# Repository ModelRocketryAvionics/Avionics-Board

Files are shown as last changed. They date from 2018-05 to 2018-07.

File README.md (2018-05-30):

# ModelRocketAvionicsPCB
'Cheap', Easy Avionics for Model Rockets!

Howdy! This is a repo for an avionics board designed for small scale model rockets. The goal of the project is to provide an easy to integrate system that provides telemetry data measurements. 

The main features are:
- 3 DOF Accelerometer (upto 24g)
- 3 DOF Gyroscope
- Barometric Pressure/Altitude sensor
- microSD Card data storage
- USB for charging, reprogramming and microSD card reading*
- Expansion header for future functionality called "Stages" (see below)

*Usb programming and microSD card reading probably won't be implemented initially.

Potential/Planned Stages/Expansion Boards:
- Radio link/communications (Provides real-time telemetry data over a short range wireless link)
- Relay/Switcher (Provides high-power switching for ignition of additional charges/engines, deploy parachutes, etc)
- Additional Sensors Expansions (Additional Sensors like GPS, etc)

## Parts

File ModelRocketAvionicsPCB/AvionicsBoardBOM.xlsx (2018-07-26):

Avionics Board BOM
Reference Part Numbers | Reference Name | Digikey Part Number | Quantitity
U1 | TM4C123GH6PM | 296-46360-1-ND | 1
R1, R15 | 100 Ohm 402 | P100DECT-ND | 2
P1 | FTSH-105-01-F-DV | SAM8796-ND | 1
R2, R3, R4, R9, R10, R11, R14 | 10k Ohm 402 | ‎CR0402-FX-1002GLF‎ (https://www.digikey.ca/product-detail/en/bourns-inc/CR0402-FX-1002GLF/CR0402-FX-1002GLFCT-ND/3592879) | 7
C1, C3, C5 | 0.01uF 402 | 1276-1494-1-ND | 3
C2, C4, C7, C8, C14, C22, C23, C24, C26, C27 | 0.1uF 402 | 490-6322-1-ND | 10
C6, C9, C11, C12, C13, C25 | 1uF 603 | 1276-1102-1-ND | 6
C10, C31 | 2.2uF 603 | 490-3296-1-ND | 1
R5, R6 | 4.7k Ohm 402 | P4.7KDCCT-ND | 2
C19, C21 | 10uF 1206 Pol | 478-10756-1-ND | 2
U5 | MPL3115A2 | MPL3115A2-ND | 1
U3 | LIS331 | 497-10134-ND | 1
C20 | 10uF 603 | 1276-1871-1-ND | 1
C28 | 10nF 402 | 445-5584-1-ND | 1
U4 | L3GD2-HTR | 497-13931-1-ND | 1
P2 | USB_Connector_ZX62-B-5PA | H125279CT-ND | 1
CON1 | microSD_Card | WM11190CT-ND | 1
C17, C18 | 24pF 402 | 1276-1670-1-ND | 2
C15, C16 | 10pF 402 | ‎GJM1555C1H100GB01D‎ (https://www.digikey.ca/product-detail/en/murata-electronics-north-america/GJM1555C1H100GB01D/490-8077-1-ND/4380363) | 2
Y1 | 16MHz | 631-1150-1-ND | 1
Y2 | 32.768kHz | 535-9034-ND | 1
U8, U9 | 16pin Female Headers | S7014-ND | 2
D3 | Geend Small LED 603 | 160-1435-1-ND | 1
P3 | JST-2 | 455-1611-ND | 1
U10 | DMG1029SV-7 | DMP2004VKDICT-ND | 1
U11 | CSS-1210TB | 563-1091-1-ND | 1
C29, C30 | 4.7uF 603 | 445-7478-1-ND | 2
C32 | 470pF 402 | 490-1300-1-ND | 1
R13 | 330 Ohm 402 | RR05P330DCT-ND | 1
D1 | Small Red LED 603 | 160-1447-1-ND | 1
D2 | B340A | B340A-FDICT-ND | 1
U6 | MCP73831 | MCP73831T-2ACI/OTCT-ND | 1
U7 | MIC5219-3.3BM5 | 576-1281-1-ND | 1
Total Number of Parts per Board |  |  | 62

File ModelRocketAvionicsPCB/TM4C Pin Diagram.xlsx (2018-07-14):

TM4C123G Pin Allocation and Function Descriptions |  |  |  |  |  |  |  |  |  | Yes
Pin Number | GPIO Name | Available | Net Name | Description Of Function | Other Functions/Peripherals |  |  |  |  | No
1 | PB6 | Yes | GRY_INT2/DRDY | Gyroscope Sensor Interrupt Pin |  |  |  |  |  | RSV
2 | VDDA | No | PWR_VDDA | Analog Power Supply+
3 | GNDA | No | PWR_GND | Analog Power Supply- (Connected to PWR_GND)
4 | PB7 | Yes | GYR_INT1 | Gyroscope Sensor Interrupt Pin
5 | PF4 | Yes | GYR_DEN | Gyroscope Data Enable Pin | `
6 | PE3 | Yes | ACC_INT1 | Accelrometer Sensor Interrupt Pin |  |  |  | PF4/SW1 | User Push Button 1
7 | PE2 | Yes | ACC_INT2 | Accelrometer Sensor Interrupt Pin
8 | PE1 | Yes
9 | PE0 | Yes
10 | PD7 | Yes
11 | VDD | No | PWR_VDD | Main Positive Power Supply
12 | GND | No | PWR_GND | Main Negative Power Supply |  | ACC_INT2 | Accelrometer Sensor Interrupt Pin
13 | PC7 | Yes |  |  |  | GYR_INT1 | Gyroscope Sensor Interrupt Pin
14 | PC6 | Yes |  |  |  | GRY_INT2/DRDY | Gyroscope Sensor Interrupt Pin
15 | PC5 | Yes |  |  |  | GYR_DEN | Gyroscope Data Enable Pin
16 | PC4 | Yes |  |  |  | ACC_INT1 | Accelrometer Sensor Interrupt Pin
17 | PA0 | RSV | PA0/U0Rx | UART0 Receive, Used in FTDI Header for debug/programming
18 | PA1 | RSV | PA1/U0Tx | UART0 Transmit, Used in FTDI Header for debug/programming
19 | PA2 | No | PA2/SSI0CLK | SPI0 Clock, Used for microSD Card or SPI Flash
20 | PA3 | No | PA3/SSI0Fss | SPI0 Chip Select, Used for microSD Card or SPI Flash
21 | PA4 | No | PA4/SSI0Rx | SPI0 Receive, Used for microSD Card or SPI Flash
22 | PA5 | No | PA5/SSI0Tx | SPI0 Transmit, Used for microSD Card or SPI Flash
23 | PA6 | Yes
24 | PA7 | Yes
25 | VDDC | No | PWR_VDDC | Internal Positive Power Supply
26 | VDD | No | PWR_VDD | Main Positive Power Supply
27 | GND | No | PWR_GND | Main Negative Power Supply
28 | PF0 | No | PF0/SW2 | User Push Button 2 and MCU Wake
29 | PF1 | No | PF1/LED_R | User Red LED, cut jumper for: GPIO, PWM Output (M1P5)
30 | PF2 | Yes | BAR_INT1 | Interrupt Pin for Barometer Sensor
31 | PF3 | Yes | BAR_INT2 | Interrupt Pin for Barometer Sensor
32 | WAKE | No | WAKE | Wake pin for low power
33 | HIB | RSV | HIB | Hibernation Output (For turning off regulator)
34 | XOSC0 | No | XOSC0 | 32.768kHz Crystal
35 | GNDX | No | XGND | 32.768kHz Crystal
36 | XOSC1 | No | XOSC1 | 32.768kHz Crystal
37 | VBAT | No | PWR_VBAT | Connected to PWR_VDD
38 | RST | No | RESET | MCU Reset (Connected to Push button)
39 | GND | No | PWR_GND | Main Negative Power Supply
40 | OSC0 | No | OSC0 | Main Oscillator 0
41 | OSC1 | No | OSC1 | Main Oscillator 0
42 | VDD | No | PWR_VDD | Main Positive Power Supply
43 | PD4 | No | USB0_DM | USB 0 Data Minus
44 | PD5 | No | USB0_DP | USB 0 Data Plus
45 | PB0 | No | PB0/USB0_ID | USB 0 OTG Id
46 | PB1 | No | PB1/USB0_VBUS | USB 0 VBUS Power Supply (5V tolerant)
47 | PB2 | No | PB2/I2C_SCL | I2C0 Clock
48 | PB3 | No | PB3/I2C_SDA | I2C0 Data
49 | PC3 | No | PC3/JTAG_TDO | JTAG Programming/Debug TDO Pin
50 | PC2 | No | PC2/JTAG_TDI | JTAG Programming/Debug TDI Pin
51 | PC1 | No | PC1/JTAG_TMS | JTAG Programming/Debug TMS Pin
52 | PC0 | No | PC0/JTAG_TCK | JTAG Programming/Debug TCK Pin
53 | PD6 | Yes
54 | VDD | No | PWR_VDD | Main Positive Power Supply
55 | GND | No | PWR_GND | Main Negative Power Supply
56 | VDDC | No | PWR_VDDC | Internal Positive Power Supply
57 | PB5 | Yes
58 | PB4 | Yes
59 | PE4 | Yes | PE4/U5Rx | UART 5 Receive
60 | PE5 | Yes | PE5/U5Tx | UART 5 Transmit
61 | PD0 | Yes | PD0/SSI1CLK | SPI1 Clock | PWM Output (M1P0)
62 | PD1 | Yes | PD1/SSI1Fss | SPI1 Chip Select | PWM Output (M1P1)
63 | PD2 | Yes | PD2/SSI1Rx | SPI1 Receive | Analog Input 5
64 | PD3 | Yes | PD3/SSI1Tx | SPI1 Transmit | Analog input 4
 |  |  |  |  | Total Header Pins
Headers | Left | Right
1 | PWR_GND | +VBAT
2 | PWR_GND | +VBAT
3 | I2C_SCL | 3V3
4 | I2C_SDA | 3V3
5 | 53 | WAKE
6 | RESET | 24
7 | 33 | 23
8 | 57 | 18
9 | 58 | 17
10 | 59 | 16
11 | 60 | 15
12 | 61 | 14
13 | 62 | 13
14 | 63 | 10
15 | 64 | 9
16 | 3V3 | PWR_GND
 | 33 | 24
 | I2C_SCL | 23
 | I2C_SDA | 18
 | Reset | 17
 | 53 | 16
 | 57 | 15
 | 58 | 14
 | 59 | 13
 | 60 | 10
 | 61 | 9
 | 62 | 8
 | 63 | 7
 | 64 | 6
 |  | 5
 |  | 4
 |  | 1

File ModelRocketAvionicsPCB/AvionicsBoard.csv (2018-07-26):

Id | Designator | Package | Quantity | Designation | Supplier and ref
1 | C1,C3,C5 | C_0402 | 3 | 0.01uF
2 | C2,C4,C7,C8,C14,C22,C24,C27 | C_0402 | 8 | 0.1uF
3 | C6,C9,C11,C12,C13,C25 | C_0603 | 6 | 1uF
4 | C10,C31 | C_0603 | 2 | 2.2uF
5 | C15,C16 | C_0402 | 2 | 10pF
6 | C17,C18 | C_0402 | 2 | 24pF
7 | C20 | C_0603 | 1 | 10uF
8 | C23,C26 | C_0402 | 2 | .1uF
9 | C28 | C_0402 | 1 | 10nF(25V)
10 | C29,C30 | C_0603 | 2 | 4.7uF
11 | C32 | C_0402 | 1 | 470pF
12 | microSD_Card | Micro_SD_WM11190CT | 1 | microSD_Card
13 | D1 | R_0603 | 1 | RED
14 | D2 | B340A | 1 | B340A
15 | P1 | FTSH-105-01-F-DV-K | 1 | FTSH-105-01-F-DV
16 | P3 | JST_B2B-EH-A(LF)(SN) | 1 | JST-2
17 | R1,R15 | R_0402 | 2 | 100
18 | R2,R3,R4,R9,R10,R11,R14 | R_0402 | 7 | 10k
19 | R5,R6 | R_0402 | 2 | 4.7k
20 | R13 | R_0402 | 1 | 330
21 | U1 | TM4C123GH6PMI | 1 | TM4C123GH6PM
22 | U3 | LIS331HH | 1 | LIS331
23 | U4 | Gyro_L3GD20HTR | 1 | L3GD20HTR
24 | U5 | MPL3115A2 | 1 | MPL3115A2
25 | U6 | MCP73831T-2ACI&slash_OT | 1 | MCP73831
26 | U7 | MIC5219-3.3YM5-TR | 1 | MIC5219-3.3BM5
27 | Y1 | 16MHz_Clock | 1 | 16Mhz
28 | P2 | USB_Connector_ZX62-B-5PA | 1 | USB_OTG
29 | JP1,JP3 | NO_Jumper | 2 | Jumper_NO_Small
30 | JP2,JP4 | NC_Jumper | 2 | Jumper_NC_Small
31 | C19,C21 | C_1206 | 2 | 10uF
32 | Y2 | Crystal_32768Hz_Radial_Can | 1 | 32.768kHz
33 | D3 | R_0603 | 1 | Led_Small
34 | U8,U9 | 16x1_Female_Header | 2 | CONNHeaderFemale16
35 | Off U11 On | CSS-1210TB | 1 | CSS-1210TB
36 | U10 | SOT563 | 1 | DMG1029SV-7

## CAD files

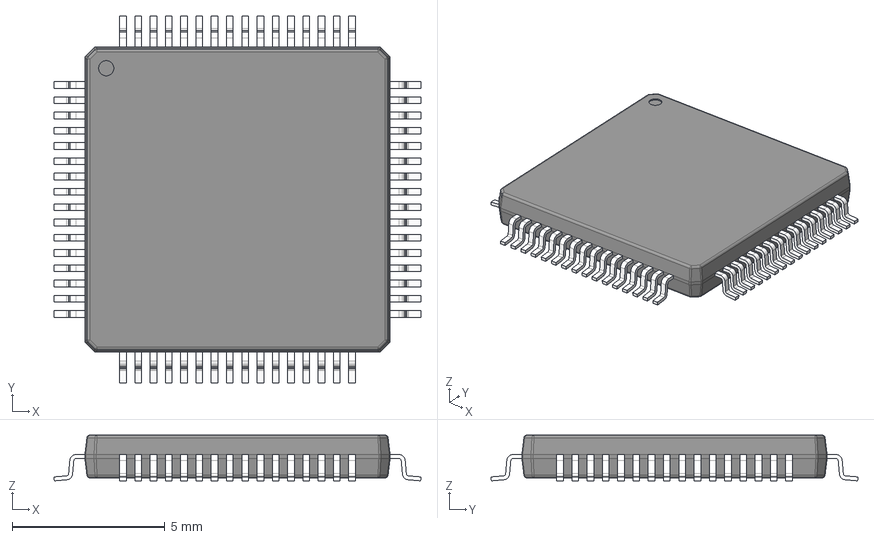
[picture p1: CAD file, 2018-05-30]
ModelRocketAvionicsPCB/PM0064A.stp
12.0 x 12.0 x 1.50 mm
BODY-QFP
LEAD-QFP x 64

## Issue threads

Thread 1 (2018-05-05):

TM4C123GH6PM Schematic is missing pin 60 (PE5)

Michael-Graves, 2018-05-05:
Currently unused so shouldn't cause any problems.

Closed 2018-05-07.

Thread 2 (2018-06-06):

USB Shield to GND

HarrisonHandley, 2018-06-06:
Need to check if all mounting pads for the USB connector should be connected to GND.

Michael-Graves, 2018-06-06:
It should

HarrisonHandley, 2018-06-06:
There's 6 pads for connecting the shield to the PCB. 4 of them have a no trace zone surrounding them. The 2 closest pads to the data pins aren't in that zone and are currently connected to GND.

Closed 2018-06-16.

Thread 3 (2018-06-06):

Jumper Footprints

HarrisonHandley, 2018-06-06:
The jumper Footprints for both NO and NC need to be done along with selecting the components.

Michael-Graves, 2018-06-06:
Can just do solder/cut jumpers where you can cut a trace or solder 2 pads together to select the state, won't need any components.

HarrisonHandley, 2018-06-06:
Should we leave the footprints at 0603 size, and then later you can connect the pads with wire. Or for the NC connections when we assemble the board.

Michael-Graves, 2018-06-06:
We should make custom footprints for NC and NO. but essentially its just a 0603 footprint with a wire between them and no solder mask

Closed 2018-06-16.

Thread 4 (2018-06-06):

Polarized Capacitors

HarrisonHandley, 2018-06-06:
Need to check if the polarized Capacitors on the sensors are required and if a SMD non-polarized cermaic capacitor can be used instead.

Michael-Graves, 2018-06-06:
Changed polarized caps to use this part: 478-10756-1-ND (1206)

Closed 2018-06-06.

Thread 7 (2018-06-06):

Allocate pins for Sensor GPIO

Michael-Graves, 2018-06-06:
Sensors need a few pins allocated for interrupts and enables. We should probably wire these in to whichever pin is convenient once we've placed the other components.

Closed 2018-06-16.

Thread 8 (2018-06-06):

Connect Headers to extra pins for Shields

HarrisonHandley, 2018-06-06:
Need to connect Headers to the extra TM4C123 and power pins so Shields can be added on later.

Michael-Graves, 2018-06-06:
~Shields~ Stages

Closed 2018-07-15.

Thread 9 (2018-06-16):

Jumper Footprint issues in Layout

HarrisonHandley, 2018-06-16:
Can't attach traces to the jumper footprints.

Closed 2018-07-15.

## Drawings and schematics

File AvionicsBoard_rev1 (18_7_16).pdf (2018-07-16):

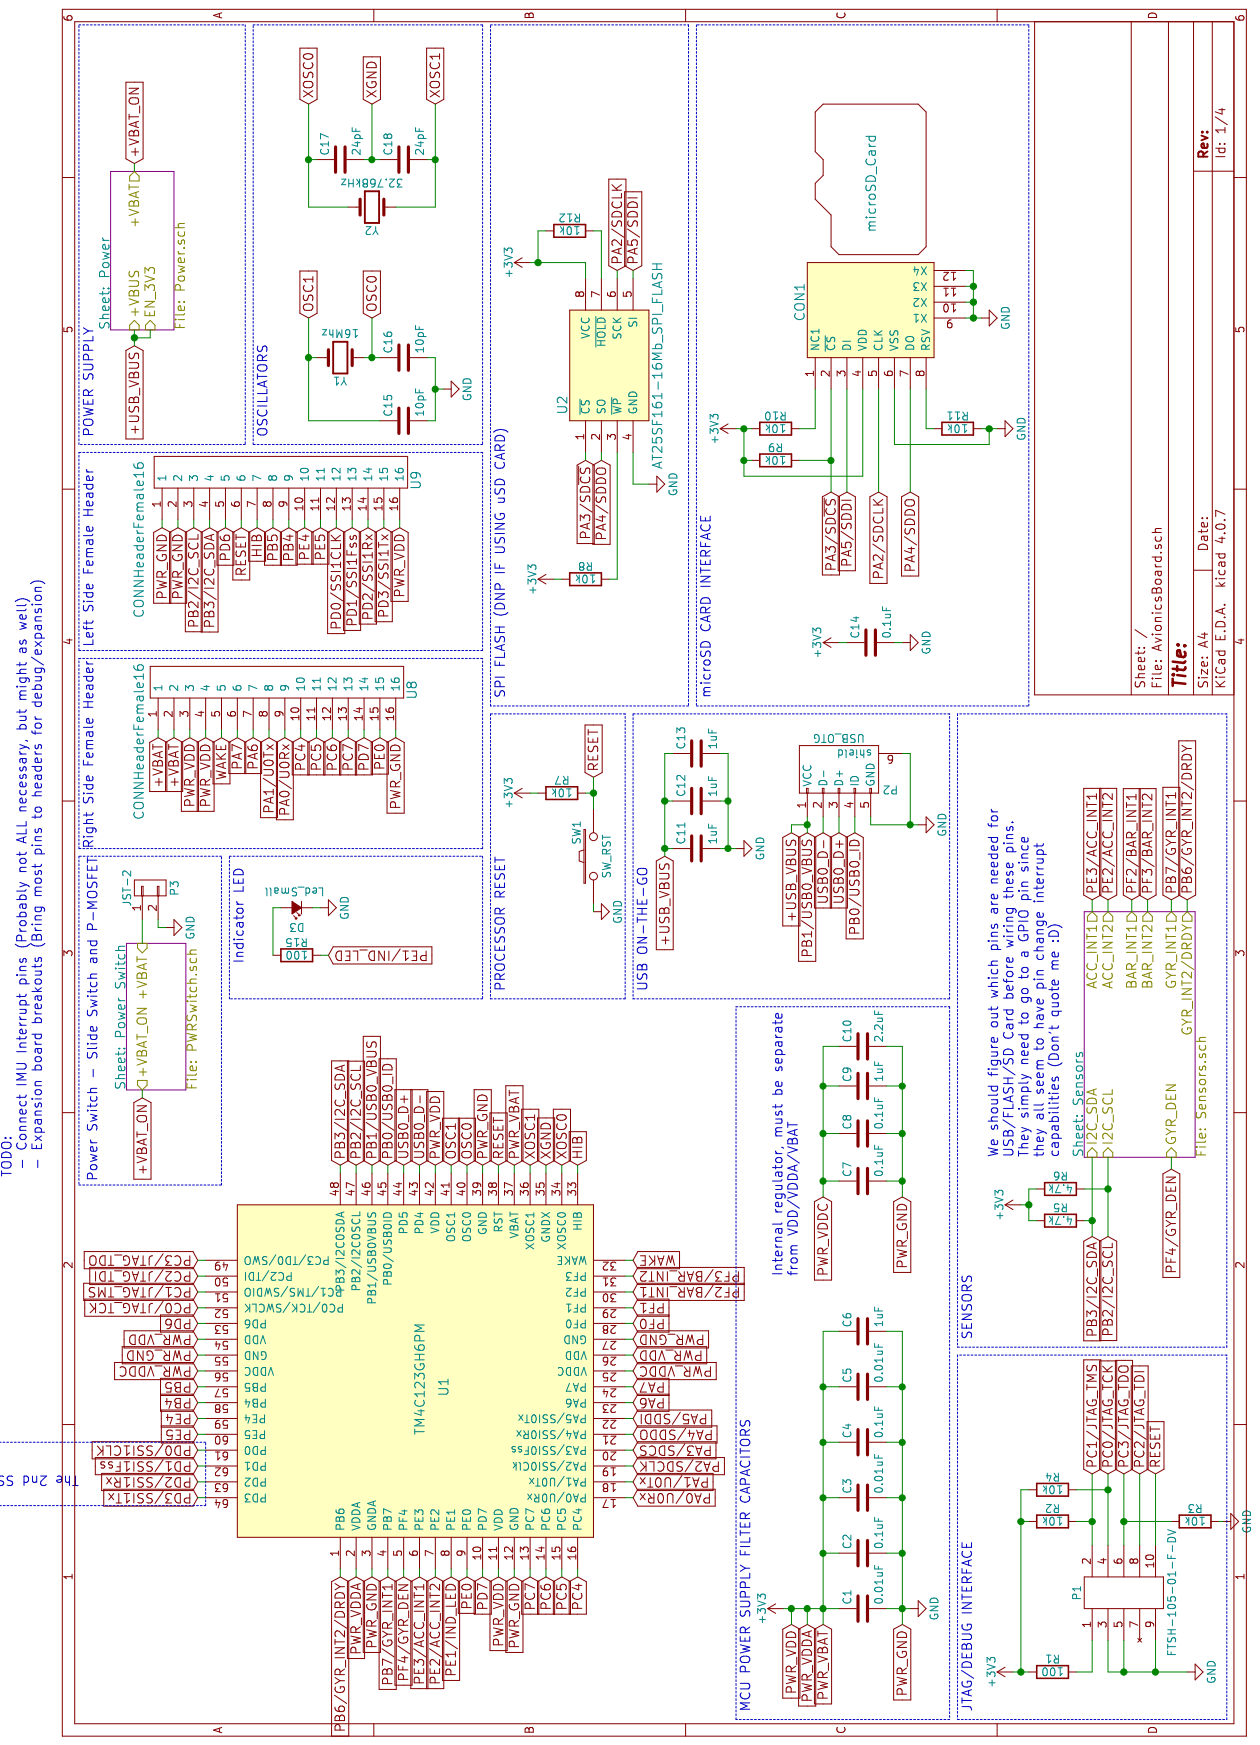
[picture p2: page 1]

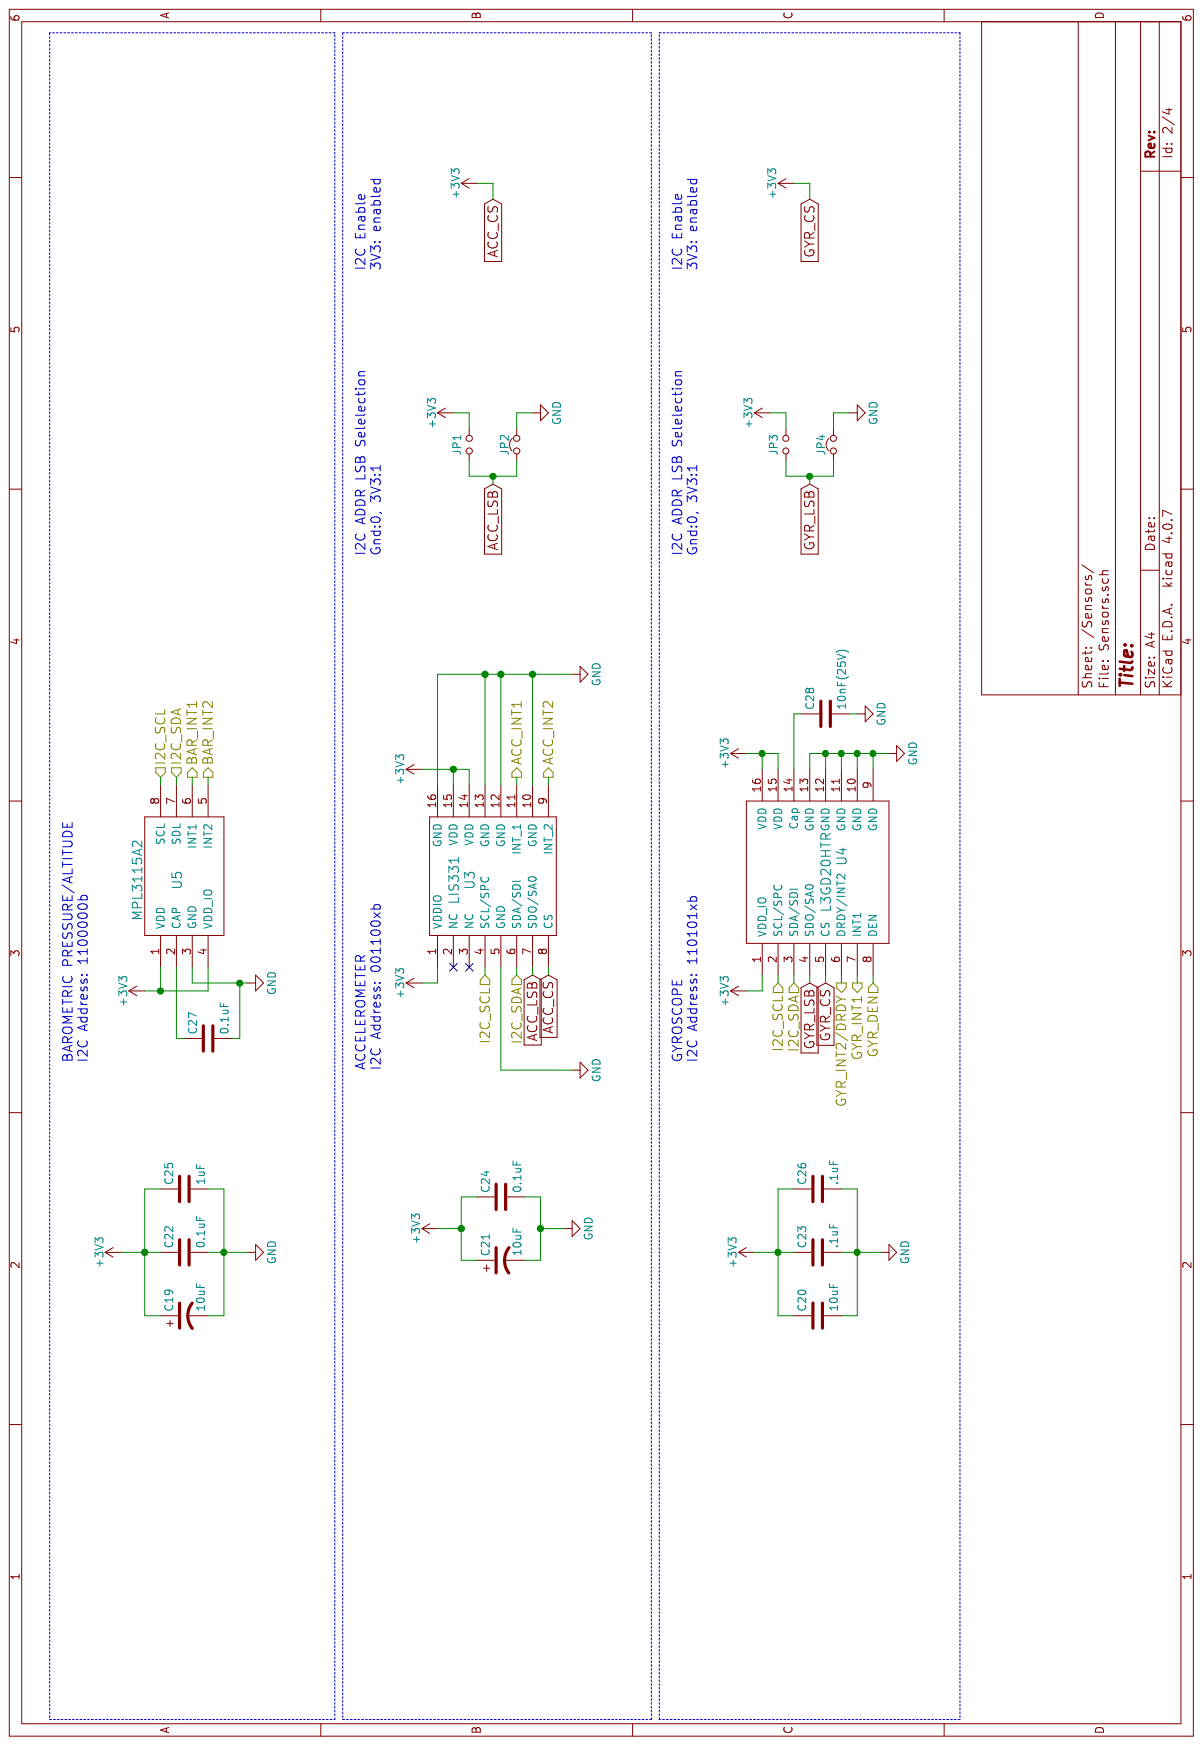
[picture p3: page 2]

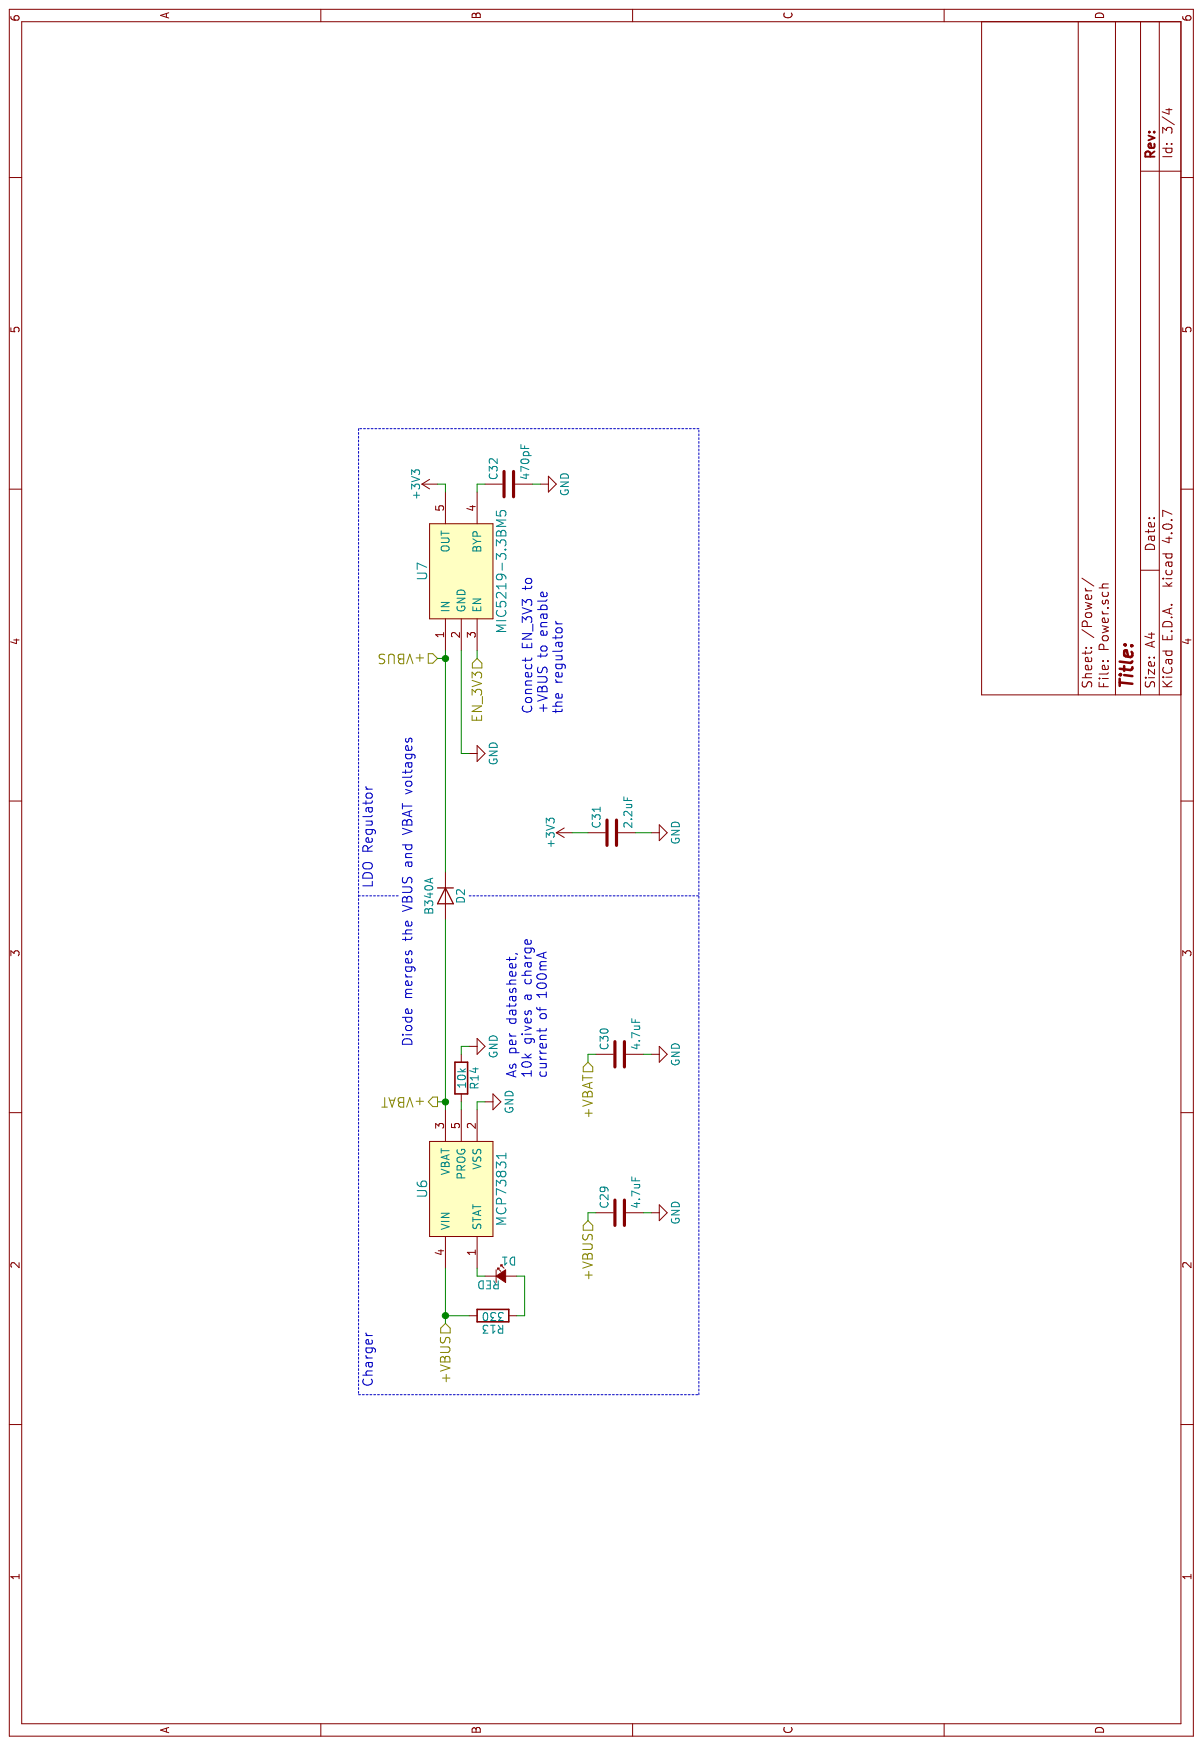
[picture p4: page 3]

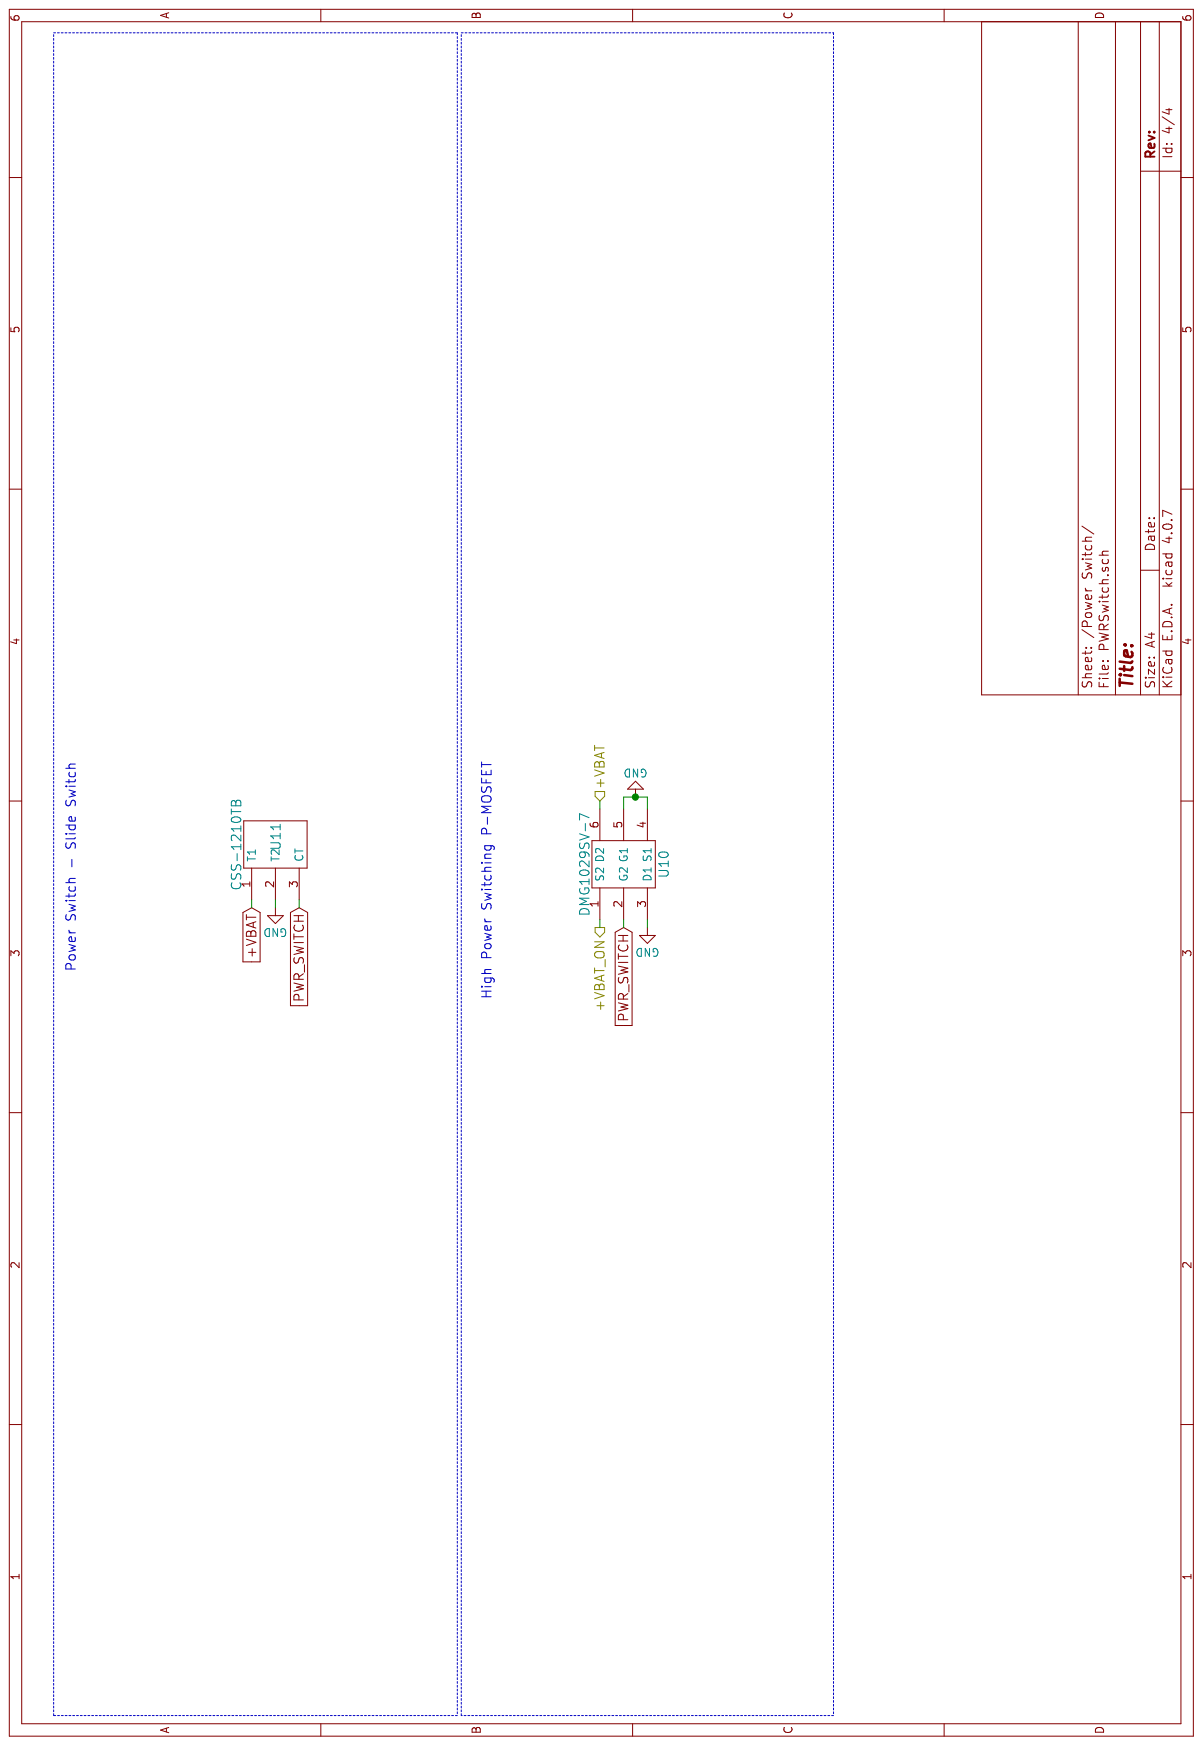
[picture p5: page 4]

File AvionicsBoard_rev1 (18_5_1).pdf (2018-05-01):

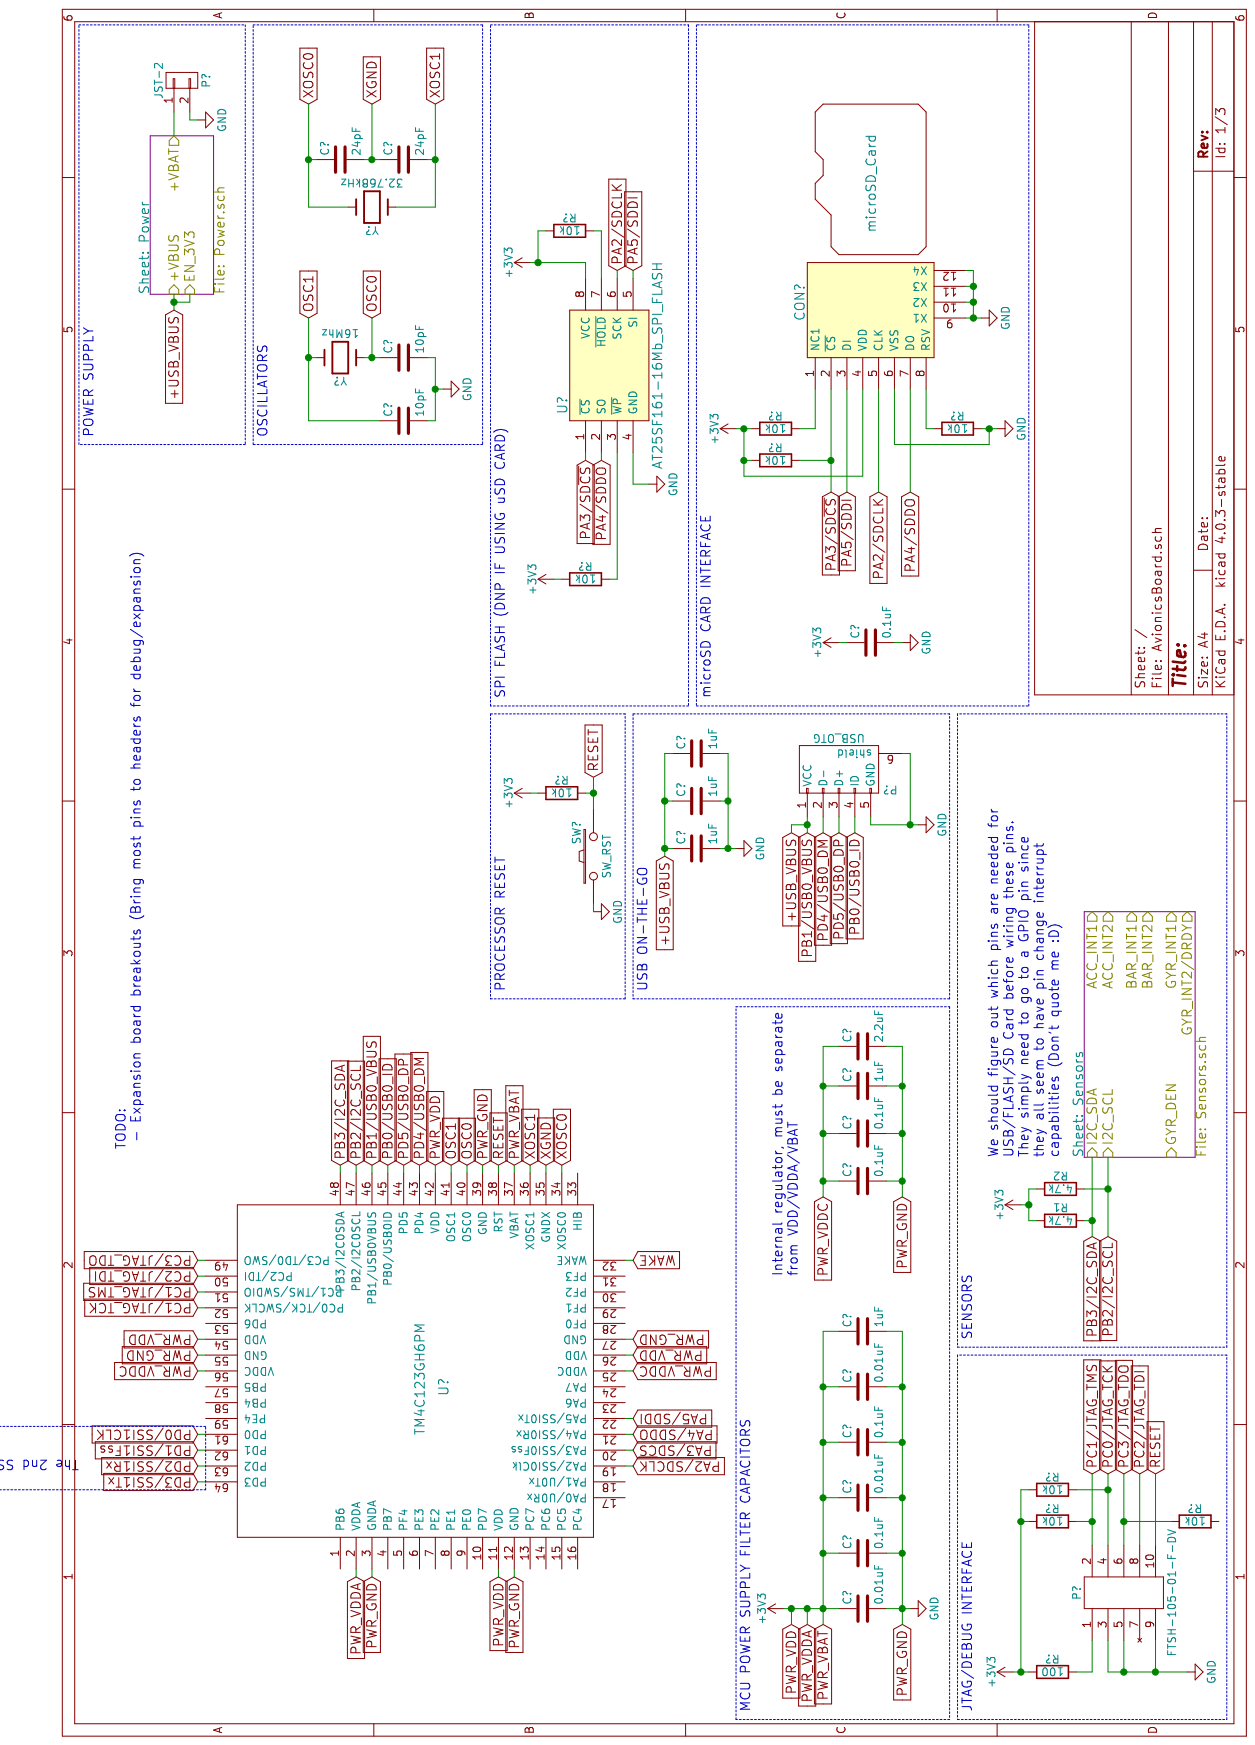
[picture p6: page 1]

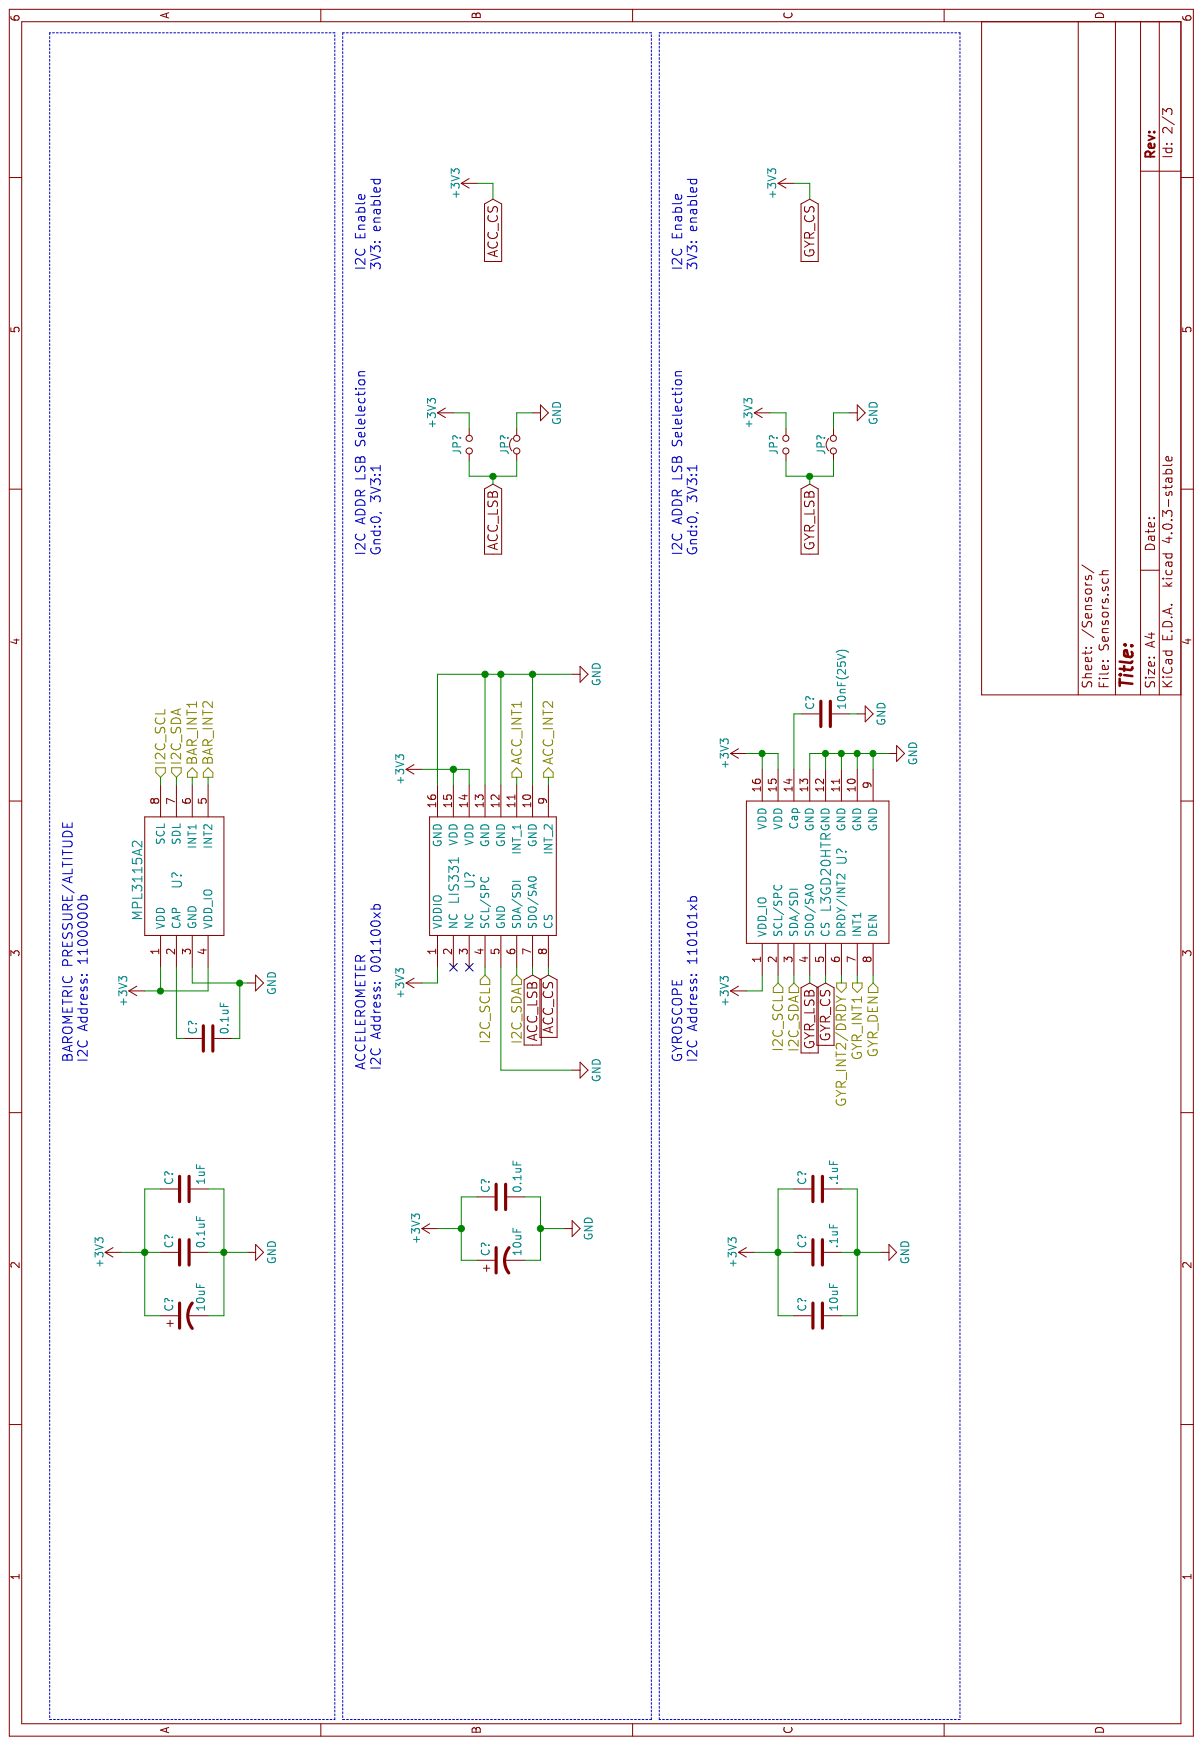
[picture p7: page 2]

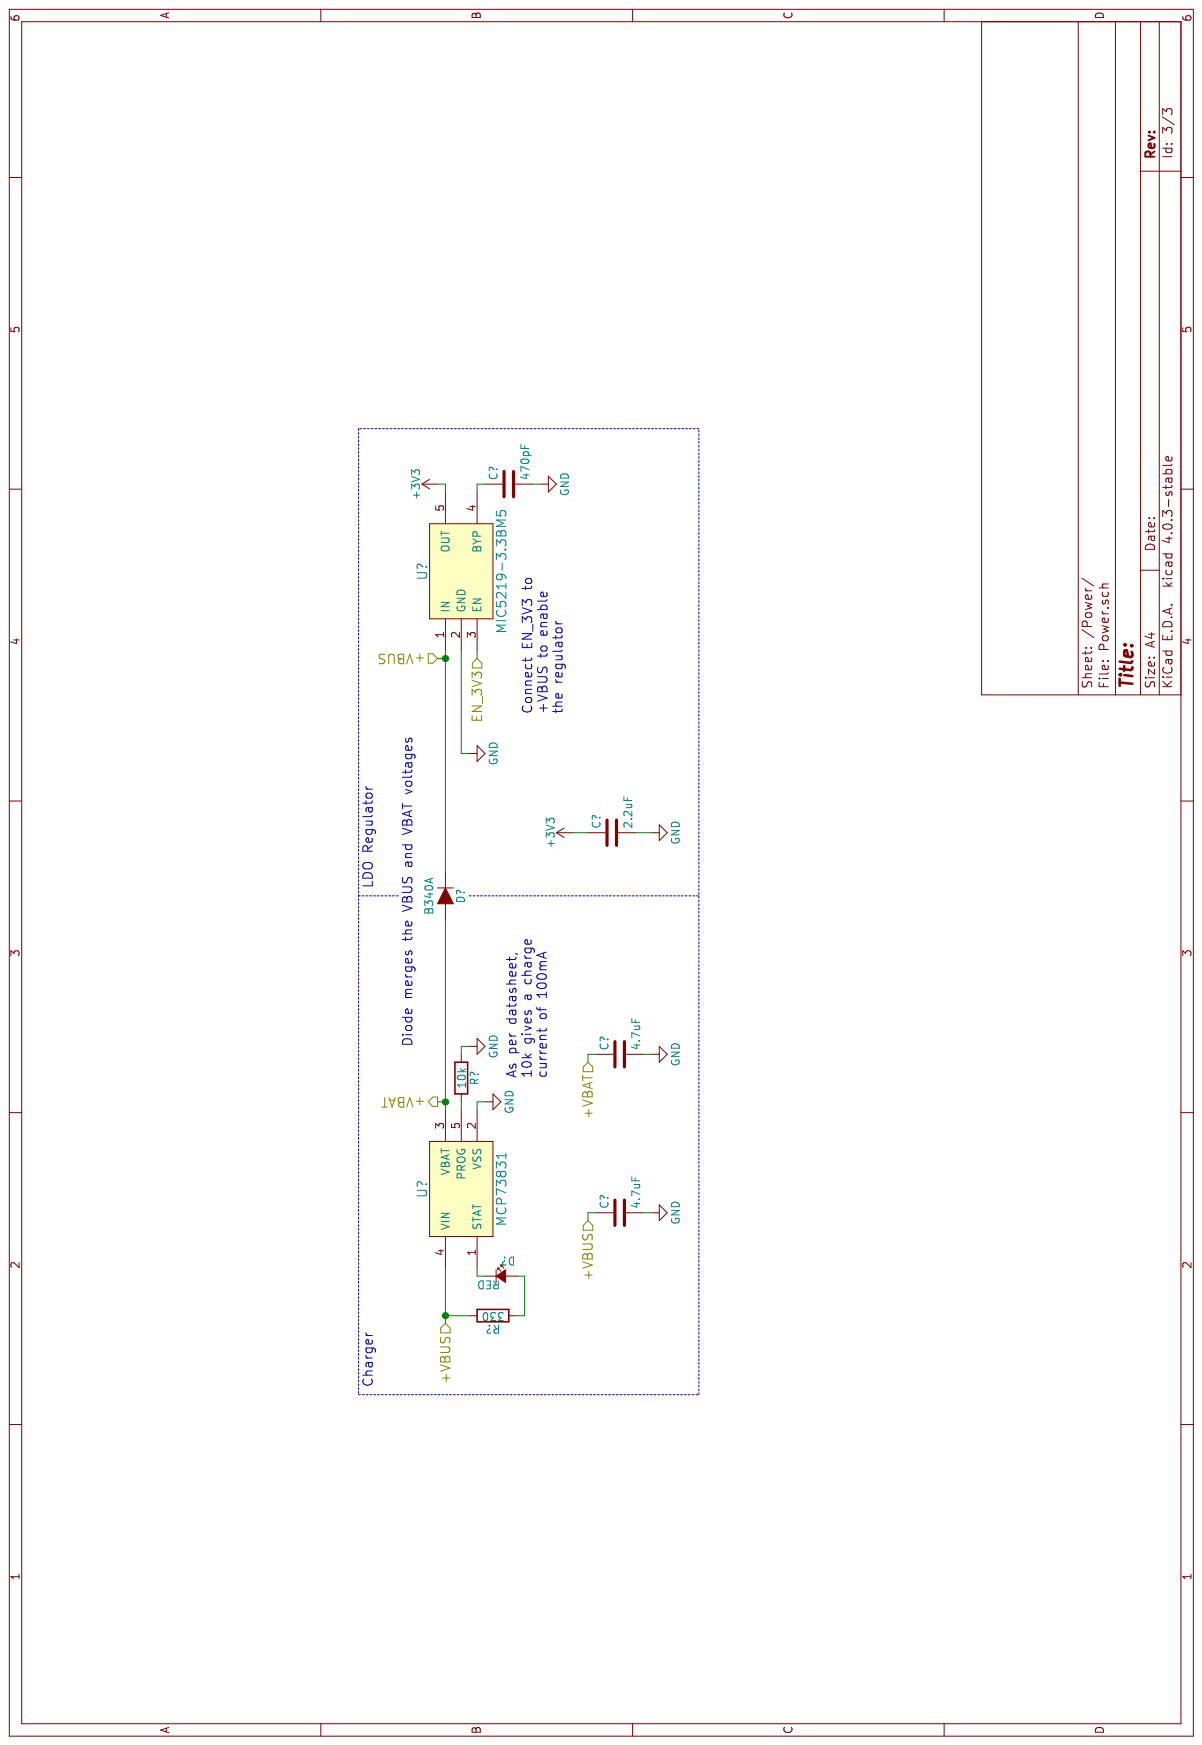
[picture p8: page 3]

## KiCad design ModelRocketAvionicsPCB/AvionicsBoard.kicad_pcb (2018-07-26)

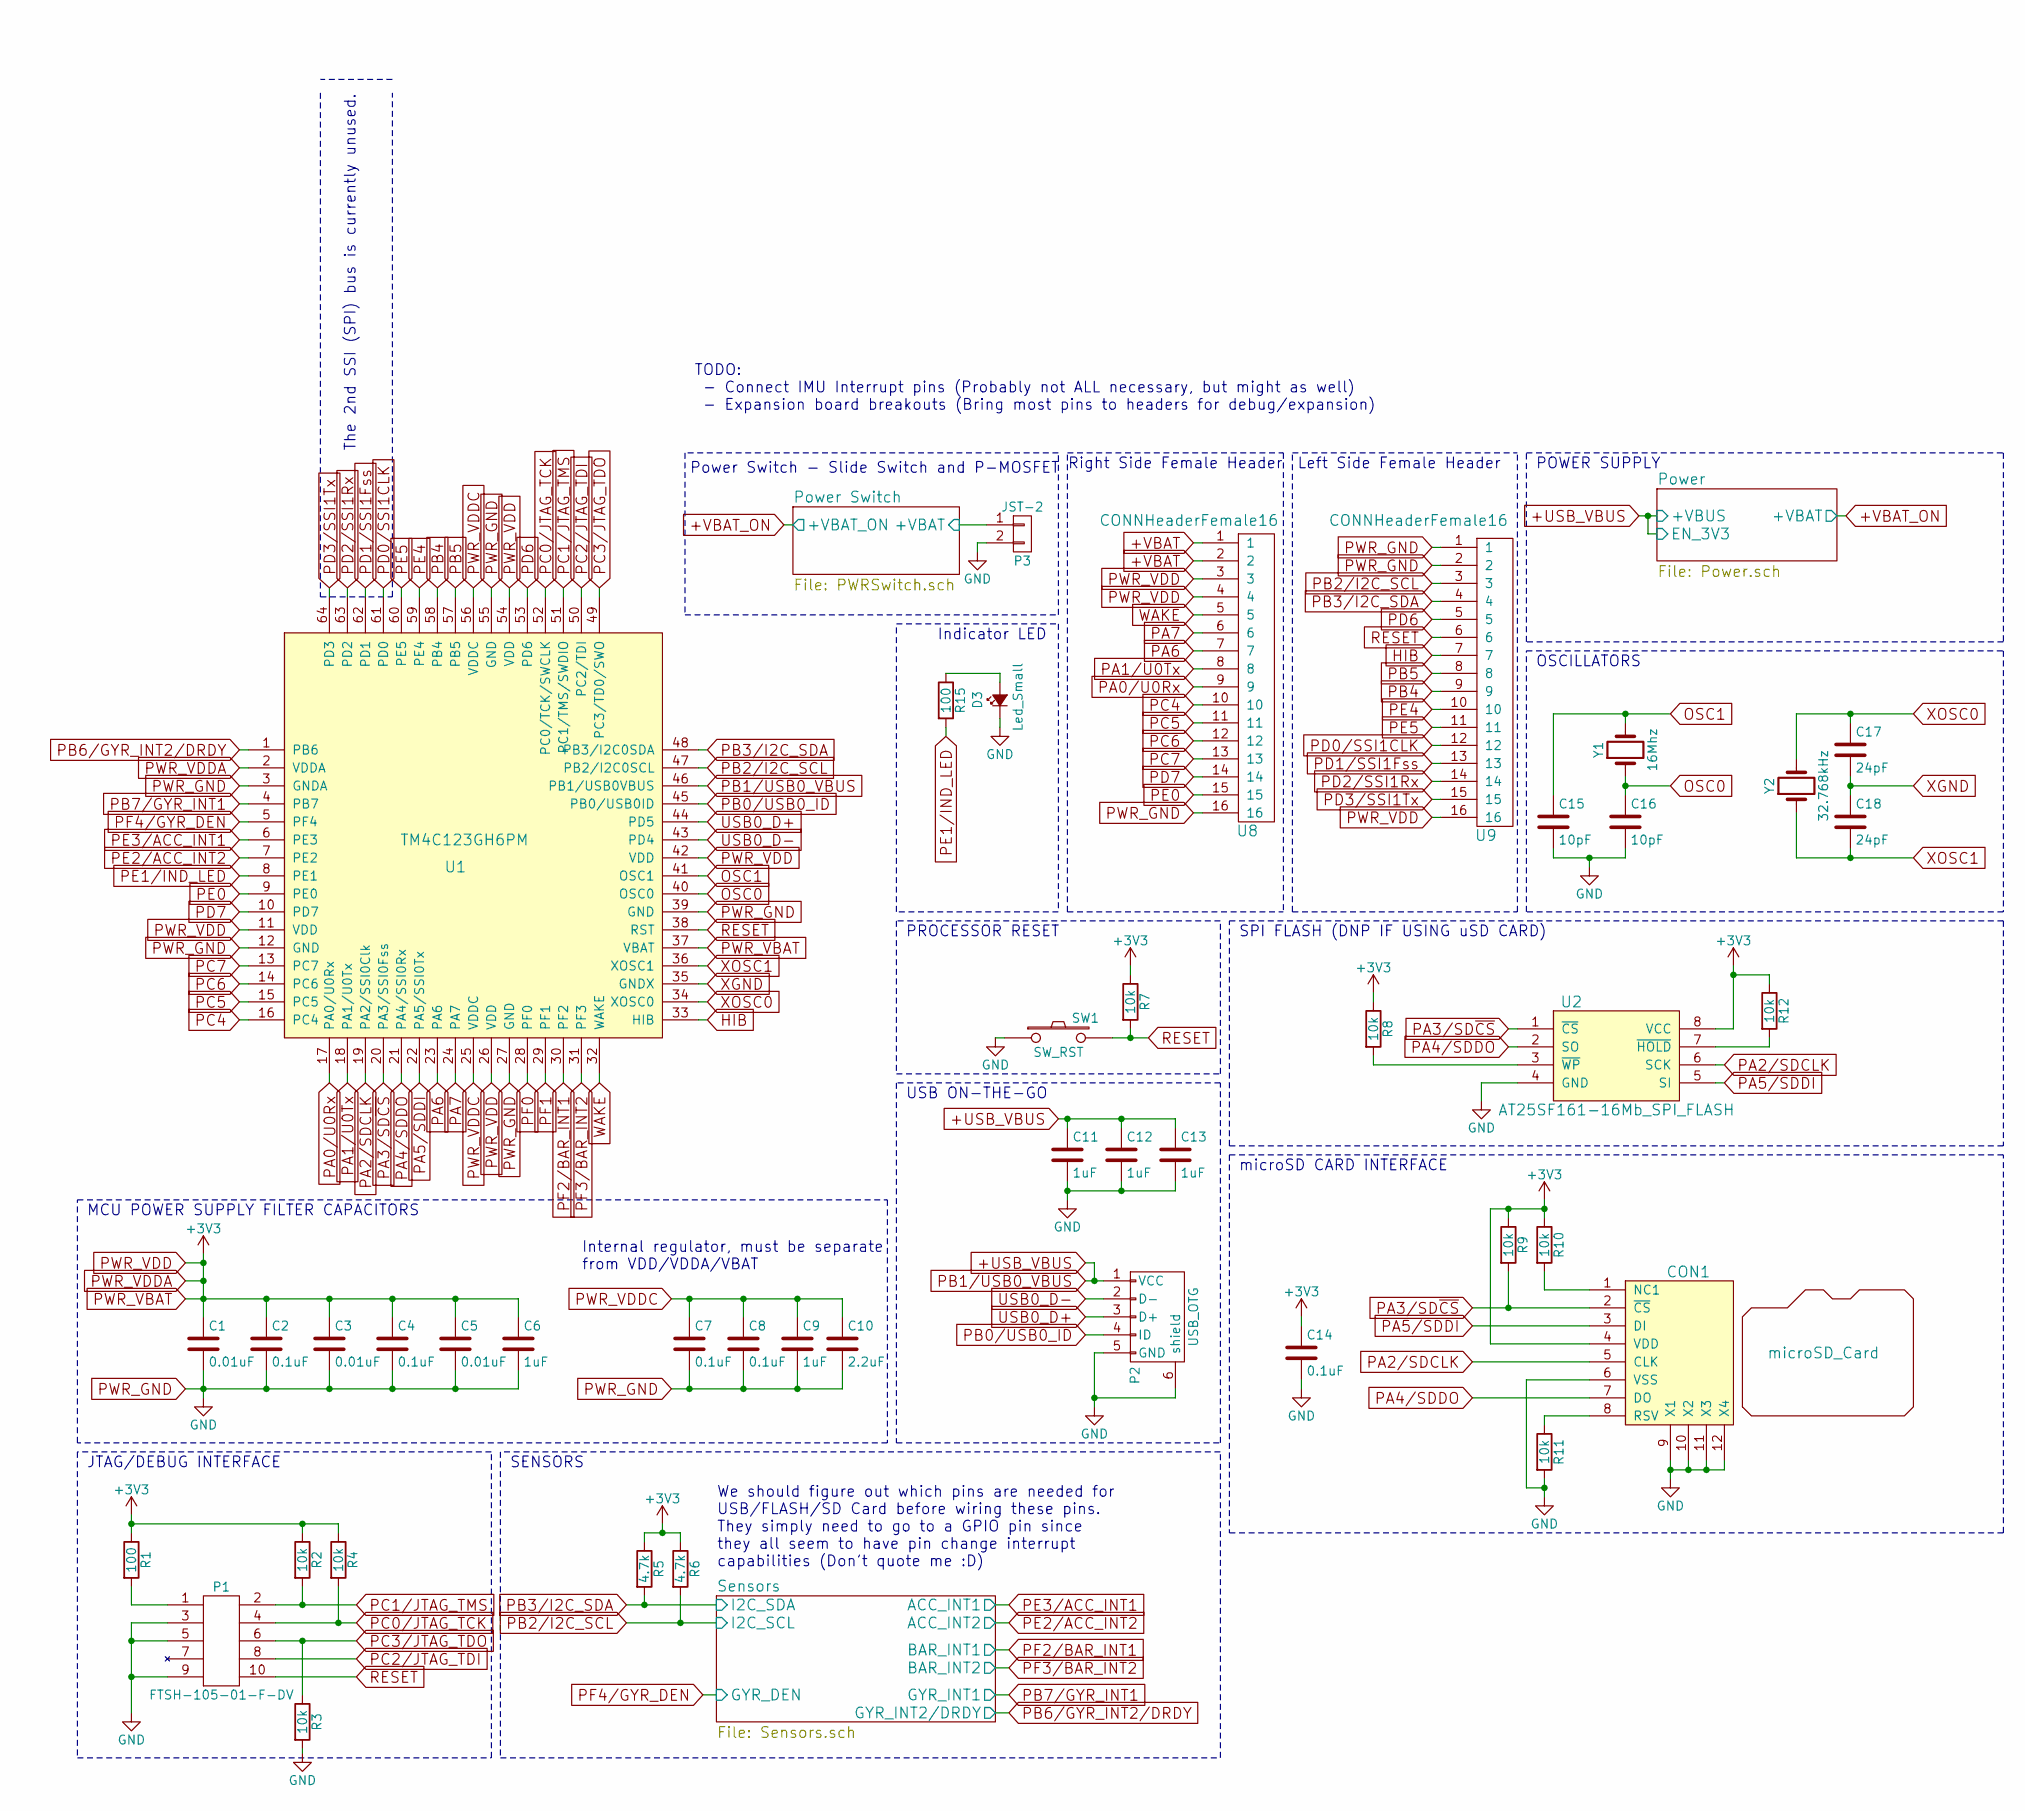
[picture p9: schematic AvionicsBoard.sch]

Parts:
C1, C3, C5: 0.01uF; C_0402; Digi-Key Part Number 478-7867-1-ND
C2, C4, C7, C8, C14: 0.1uF; C_0402; Digi-Key Part Number 587-4552-1-ND
C6, C9, C11, C12, C13: 1uF; C_0603; Digi-Key Part Number 490-1543-1-ND
C10: 2.2uF; C_0603; Digi-Key Part Number 490-3296-1-ND
C15, C16: 10pF; C_0402; Digi-Key Part Number 712-1252-1-ND
C17: 24pF; C_0402; Digi-Key Part Number 478-10149-1-ND
C18: 24pF; C_0402
CON1: microSD_Card; Micro_SD_WM11190CT; Digi-Key Part Number WM11190CT-ND
D3: Led_Small; R_0603; Digi-Key Number 160-1435-1-ND
P1: FTSH-105-01-F-DV; FTSH-105-01-F-DV-K; Digi-Key Part Number SAM8796-ND
P2: USB_OTG; USB_Connector_ZX62-B-5PA; Digi-Key Part Number H125279CT-ND
P3: JST-2; JST_B2B-EH-A(LF)(SN); Digi-Key Part Number 455-1611-ND
R1, R15: 100; R_0402; Digi-Key Part Number P100DECT-ND
R2, R3, R4, R7, R8, R9, R10, R11, R12: 10k; R_0402; Digi-Key Part Number 311-10.0KLRCT-ND
R5, R6: 4.7k; R_0402; Digi-Key Part Number P4.7KDCCT-ND
SW1: SW_RST; Push_Button_B3S-1000; Digi-Key Part Number SW415-ND
U1: TM4C123GH6PM; TM4C123GH6PMI; Digi-Key Part Number 296-46360-1-ND
U2: AT25SF161-16Mb_SPI_FLASH; Flash_Mem_AT25SF161-SSHD; Digi-Key Part Number 1265-1230-1-ND
U8, U9: CONNHeaderFemale16; 16x1_Female_Header
Y1: 16Mhz; 16MHz_Clock; Manufacturer Part No NX5032GA-16.000000MHZ-LN-CD-1; Digi-Key Part Number 631-1150-1-ND
Y2: 32.768kHz; Crystal_32768Hz_Radial_Can; Digi-Key Part Number 535-9034-ND

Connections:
+USB_VBUS: C11.1, C12.1, C13.1, P2.1 (VCC), U1.46 (PB1/USB0VBUS); also elsewhere on the board
+VBAT: P3.1, U8.1, U8.2; also elsewhere on the board
ACC_CS: C1.1, C2.1, C3.1, C4.1, C5.1, C6.1, C14.1, CON1.4 (VDD), R1.1, R2.1, R4.1, R5.1, R6.1, R7.1, R8.1, R9.1, R10.1, R12.1, U1.2 (VDDA), U1.11 (VDD), U1.26 (VDD), U1.37 (VBAT), U1.42 (VDD), U1.54 (VDD), U2.8 (VCC), U8.3, U8.4, U9.16; also elsewhere on the board
HIB: U1.33 (HIB), U9.7
unnamed 10: CON1.1 (NC1), R10.2; also elsewhere on the board
unnamed 11: CON1.8 (RSV), R11.1; also elsewhere on the board
unnamed: D3.2 (A), R15.1
unnamed: P1.1 (3V3), R1.2
unnamed: R8.2, U2.3 (~WP)
unnamed: R12.2, U2.7 (~HOLD)
OSC0: C16.1, U1.40 (OSC0), Y1.1
OSC1: C15.1, U1.41 (OSC1), Y1.2
PA0/U0Rx: U1.17 (PA0/U0Rx), U8.9
PA1/U0Tx: U1.18 (PA1/U0Tx), U8.8
PA2/SDCLK: CON1.5 (CLK), U1.19 (PA2/SSI0Clk), U2.6 (SCK); also elsewhere on the board
PA3/SD~CS: CON1.2 (~CS), R9.2, U1.20 (PA3/SSI0Fss), U2.1 (~CS); also elsewhere on the board
PA4/SDDO: CON1.7 (DO), U1.21 (PA4/SSI0Rx), U2.2 (SO); also elsewhere on the board
PA5/SDDI: CON1.3 (DI), U1.22 (PA5/SSI0Tx), U2.5 (SI); also elsewhere on the board
PA6: U1.23 (PA6), U8.7
PA7: U1.24 (PA7), U8.6
PB0/USB0_ID: P2.4 (ID), U1.45 (PB0/USB0ID)
PB2/I2C_SCL: R6.2, U1.47 (PB2/I2C0SCL), U9.3; also elsewhere on the board
PB3/I2C_SDA: R5.2, U1.48 (PB3/I2C0SDA), U9.4; also elsewhere on the board
PB4: U1.58 (PB4), U9.9
PB5: U1.57 (PB5), U9.8
PB6/GYR_INT2/DRDY: U1.1 (PB6); also elsewhere on the board
PB7/GYR_INT1: U1.4 (PB7); also elsewhere on the board
PC0/JTAG_TCK: P1.4 (JTAG_TCK), R4.2, U1.52 (PC0/TCK/SWCLK)
PC1/JTAG_TMS: P1.2 (JTAG_TMS), R2.2, U1.51 (PC1/TMS/SWDIO)
PC2/JTAG_TDI: P1.8 (JTAG_TDO), U1.50 (PC2/TDI)
PC3/JTAG_TDO: P1.6 (JTAG_TDO), R3.1, U1.49 (PC3/TD0/SWO)
PC4: U1.16 (PC4), U8.10
PC5: U1.15 (PC5), U8.11
PC6: U1.14 (PC6), U8.12
PC7: U1.13 (PC7), U8.13
PD0/SSI1CLK: U1.61 (PD0), U9.12
PD1/SSI1Fss: U1.62 (PD1), U9.13
PD2/SSI1Rx: U1.63 (PD2), U9.14
PD3/SSI1Tx: U1.64 (PD3), U9.15
PD6: U1.53 (PD6), U9.5
PD7: U1.10 (PD7), U8.14
PE0: U1.9 (PE0), U8.15
PE1/IND_LED: R15.2, U1.8 (PE1)
PE2/ACC_INT2: U1.7 (PE2); also elsewhere on the board
PE3/ACC_INT1: U1.6 (PE3); also elsewhere on the board
PE4: U1.59 (PE4), U9.10
PE5: U1.60 (PE5), U9.11
PF0: U1.28 (PF0)
PF1: U1.29 (PF1)
PF2/BAR_INT1: U1.30 (PF2); also elsewhere on the board
PF3/BAR_INT2: U1.31 (PF3); also elsewhere on the board
PF4/GYR_DEN: U1.5 (PF4); also elsewhere on the board
PWR_GND: C1.2, C2.2, C3.2, C4.2, C5.2, C6.2, C7.2, C8.2, C9.2, C10.2, C11.2, C12.2, C13.2, C14.2, C15.2, C16.2, CON1.6 (VSS), CON1.9 (X1), CON1.10 (X2), CON1.11 (X3), CON1.12 (X4), D3.1 (K), P1.3 (GND), P1.5 (GND), P1.9 (GND), P2.5 (GND), P2.6 (shield), P3.2, R3.2, R11.2, SW1.1, U1.3 (GNDA), U1.12 (GND), U1.27 (GND), U1.39 (GND), U1.55 (GND), U2.4 (GND), U8.16, U9.1, U9.2; also elsewhere on the board
PWR_VDDC: C7.1, C8.1, C9.1, C10.1, U1.25 (VDDC), U1.56 (VDDC)
RESET: P1.10 (RST_N), R7.2, SW1.2, U1.38 (RST), U9.6
USB0_D+: P2.3 (D+), U1.44 (PD5)
USB0_D-: P2.2 (D-), U1.43 (PD4)
WAKE: U1.32 (WAKE), U8.5
XGND: C17.2, C18.1, U1.35 (GNDX)
XOSC0: C17.1, U1.34 (XOSC0), Y2.2
XOSC1: C18.2, U1.36 (XOSC1), Y2.1

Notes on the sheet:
We should figure out which pins are needed for USB/FLASH/SD Card before wiring these pins. They simply need to go to a GPIO pin since they all seem to have pin change interrupt capabilities (Don't quote me :D)
JTAG/DEBUG INTERFACE
SENSORS
MCU POWER SUPPLY FILTER CAPACITORS
Internal regulator, must be separate from VDD/VDDA/VBAT
microSD CARD INTERFACE
SPI FLASH (DNP IF USING uSD CARD)
USB ON-THE-GO
TODO: - Connect IMU Interrupt pins (Probably not ALL necessary, but might as well) - Expansion board breakouts (Bring most pins to headers for debug/expansion)
The 2nd SSI (SPI) bus is currently unused.
OSCILLATORS
PROCESSOR RESET
POWER SUPPLY
Right Side Female Header
Left Side Female Header
Power Switch - Slide Switch and P-MOSFET
Indicator LED

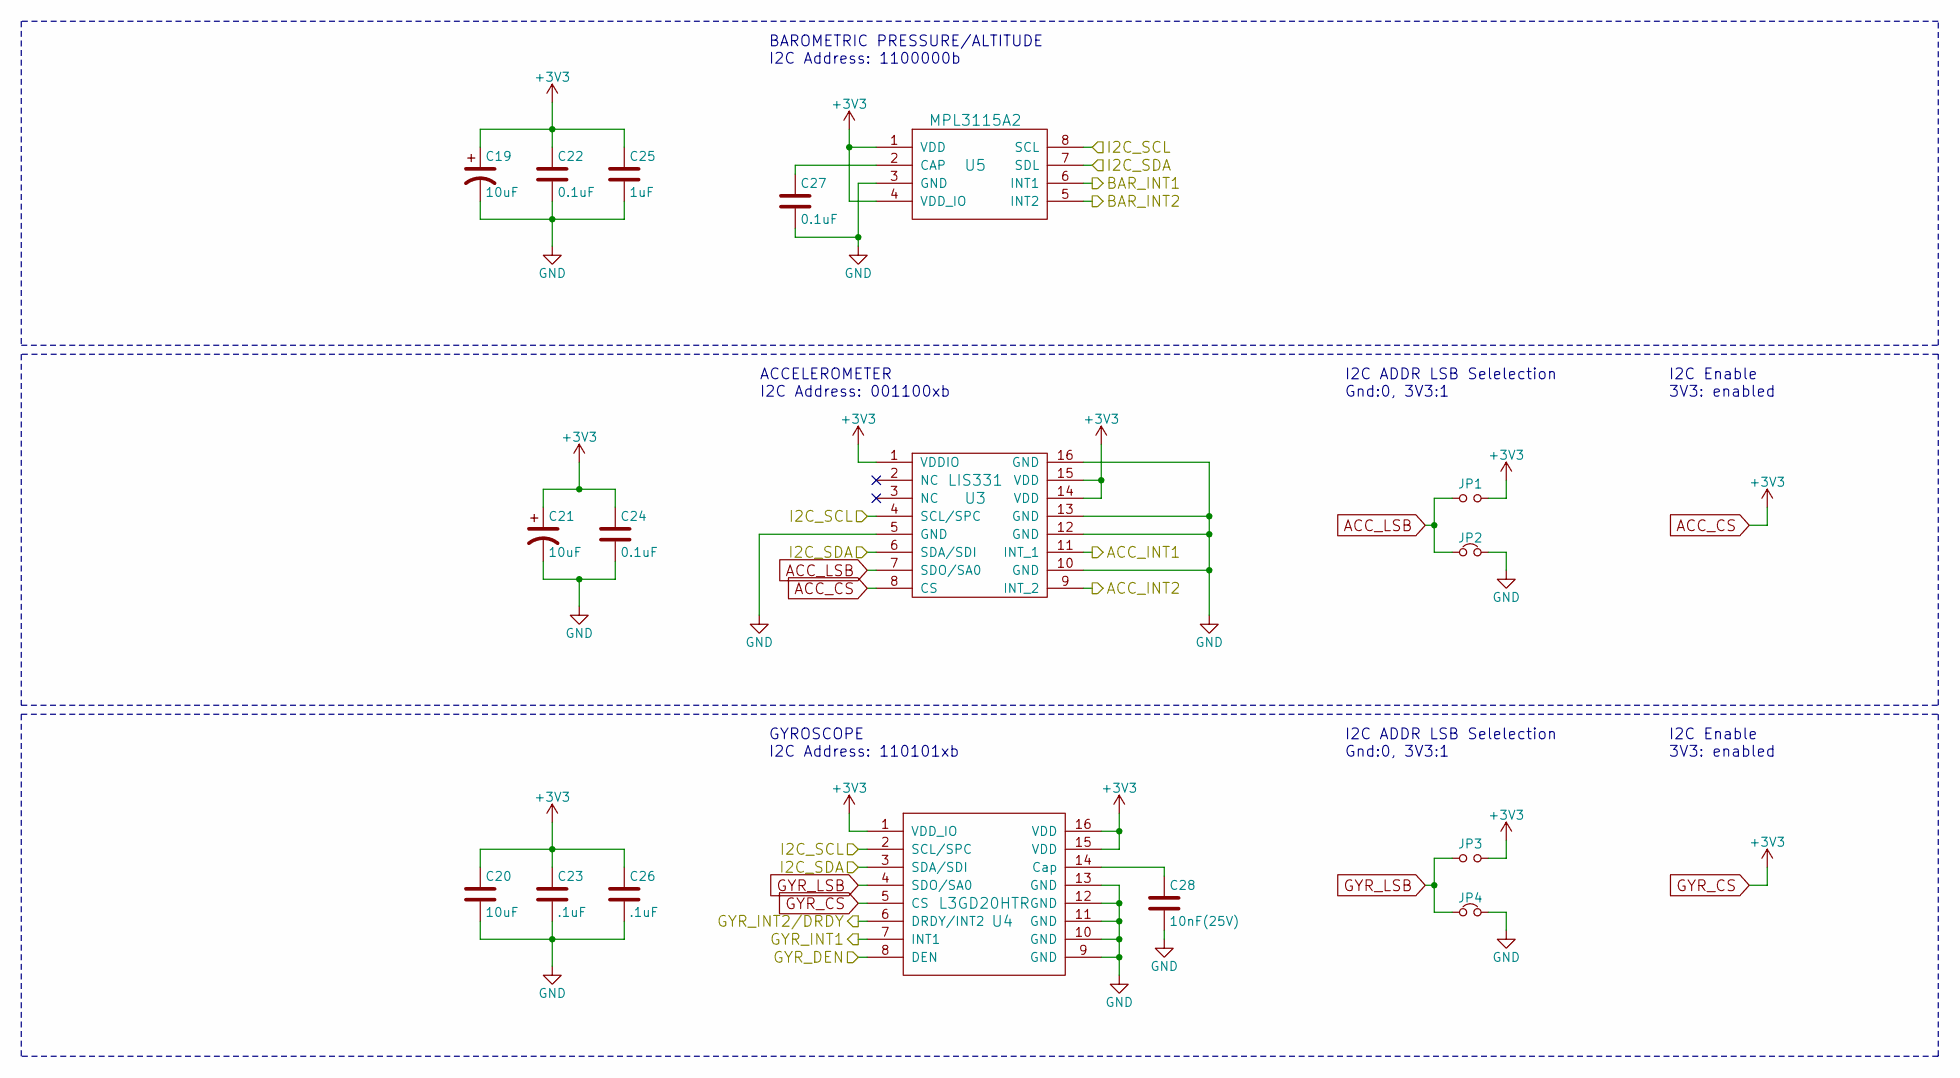
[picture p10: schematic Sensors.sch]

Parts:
C19, C21: 10uF; C_1206; Digi-Key Part Number 478-10756-1-ND
C20: 10uF; C_0603; Digi-Key Part Number 1276-1871-1-ND
C22, C24, C27: 0.1uF; C_0402; Digi-Key Part Number 587-4552-1-ND
C23, C26: .1uF; C_0402; Digi-Key Part Number 587-4552-1-ND
C25: 1uF; C_0603; Digi-Key Part Number 490-1543-1-ND
C28: 10nF(25V); C_0402; Digi-Key Part Number 478-7867-1-ND
JP1, JP3: Jumper_NO_Small; NO_Jumper
JP2, JP4: Jumper_NC_Small; NC_Jumper
U3: LIS331; LIS331HH; Digi-Key Part Number 497-10134-ND
U4: L3GD20HTR; Gyro_L3GD20HTR; Digi-Key Part Number 497-13931-1-ND
U5: MPL3115A2; Digi-Key Part Number MPL3115A2-ND

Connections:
ACC_CS: C19.1, C20.1, C21.1, C22.1, C23.1, C24.1, C25.1, C26.1, JP1.2, JP3.2, U3.1 (VDDIO), U3.8 (CS), U3.14 (VDD), U3.15 (VDD), U4.1 (VDD_IO), U4.5 (CS), U4.15 (VDD), U4.16 (VDD), U5.1 (VDD), U5.4 (VDD_IO); also elsewhere on the board
ACC_LSB: JP1.1, JP2.1, U3.7 (SDO/SA0)
GYR_LSB: JP3.1, JP4.1, U4.4 (SDO/SA0)
unnamed: C27.1, U5.2 (CAP)
unnamed: C28.1, U4.14 (Cap)
PB2/I2C_SCL: U3.4 (SCL/SPC), U4.2 (SCL/SPC), U5.8 (SCL); also elsewhere on the board
PB3/I2C_SDA: U3.6 (SDA/SDI), U4.3 (SDA/SDI), U5.7 (SDL); also elsewhere on the board
PB6/GYR_INT2/DRDY: U4.6 (DRDY/INT2); also elsewhere on the board
PB7/GYR_INT1: U4.7 (INT1); also elsewhere on the board
PE2/ACC_INT2: U3.9 (INT_2); also elsewhere on the board
PE3/ACC_INT1: U3.11 (INT_1); also elsewhere on the board
PF2/BAR_INT1: U5.6 (INT1); also elsewhere on the board
PF3/BAR_INT2: U5.5 (INT2); also elsewhere on the board
PF4/GYR_DEN: U4.8 (DEN); also elsewhere on the board
PWR_GND: C19.2, C20.2, C21.2, C22.2, C23.2, C24.2, C25.2, C26.2, C27.2, C28.2, JP2.2, JP4.2, U3.5 (GND), U3.10 (GND), U3.12 (GND), U3.13 (GND), U3.16 (GND), U4.9 (GND), U4.10 (GND), U4.11 (GND), U4.12 (GND), U4.13 (GND), U5.3 (GND); also elsewhere on the board

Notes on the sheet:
I2C ADDR LSB Selelection Gnd:0, 3V3:1
I2C Enable 3V3: enabled
ACCELEROMETER I2C Address: 001100xb
BAROMETRIC PRESSURE/ALTITUDE I2C Address: 1100000b
GYROSCOPE I2C Address: 110101xb

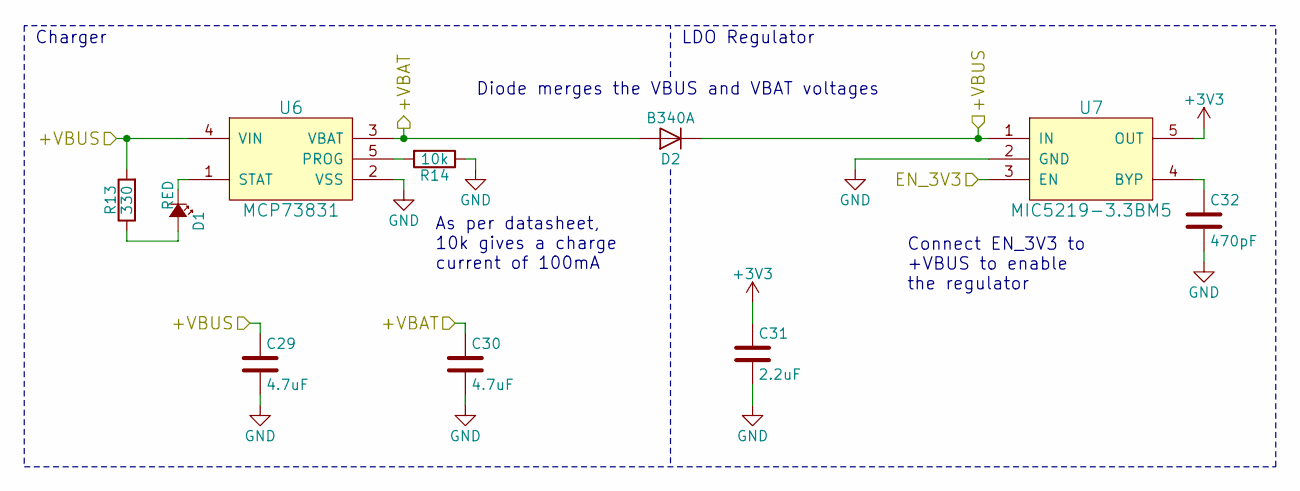
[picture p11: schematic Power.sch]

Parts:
C29, C30: 4.7uF; C_0603; Rated Voltage 16V; Digi-Key Part Number 445-7478-1-ND
C31: 2.2uF; C_0603; Digi-Key Part Number 490-10486-6-ND
C32: 470pF; C_0402; Digi-Key Part Number 490-1300-1-ND
D1: RED; R_0603; Digi-Key Part Number 160-1447-1-ND
D2: B340A; Digi-Key Part Number B340A-FDICT-ND
R13: 330; R_0402; Digi-Key Part Number RR05P330DCT-ND
R14: 10k; R_0402; Digi-Key Part Number 311-10.0KLRCT-ND
U6: MCP73831; MCP73831T-2ACI&slash_OT; Digi-Key Part Number MCP73831T-2ACI/OTCT-ND
U7: MIC5219-3.3BM5; MIC5219-3.3YM5-TR; Digi-Key Part Number 576-1281-1-ND

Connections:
+USB_VBUS: C29.1, D2.1 (K), R13.2, U6.4 (VIN), U7.1 (IN), U7.3 (EN); also elsewhere on the board
+VBAT_ON: C30.1, D2.2 (A), U6.3 (VBAT); also elsewhere on the board
ACC_CS: C31.1, U7.5 (OUT); also elsewhere on the board
unnamed: C32.1, U7.4 (BYP)
unnamed: D1.1 (K), U6.1 (STAT)
unnamed: D1.2 (A), R13.1
unnamed: R14.2, U6.5 (PROG)
PWR_GND: C29.2, C30.2, C31.2, C32.2, R14.1, U6.2 (VSS), U7.2 (GND); also elsewhere on the board

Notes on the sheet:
Diode merges the VBUS and VBAT voltages
Charger
LDO Regulator
As per datasheet, 10k gives a charge current of 100mA
Connect EN_3V3 to +VBUS to enable the regulator

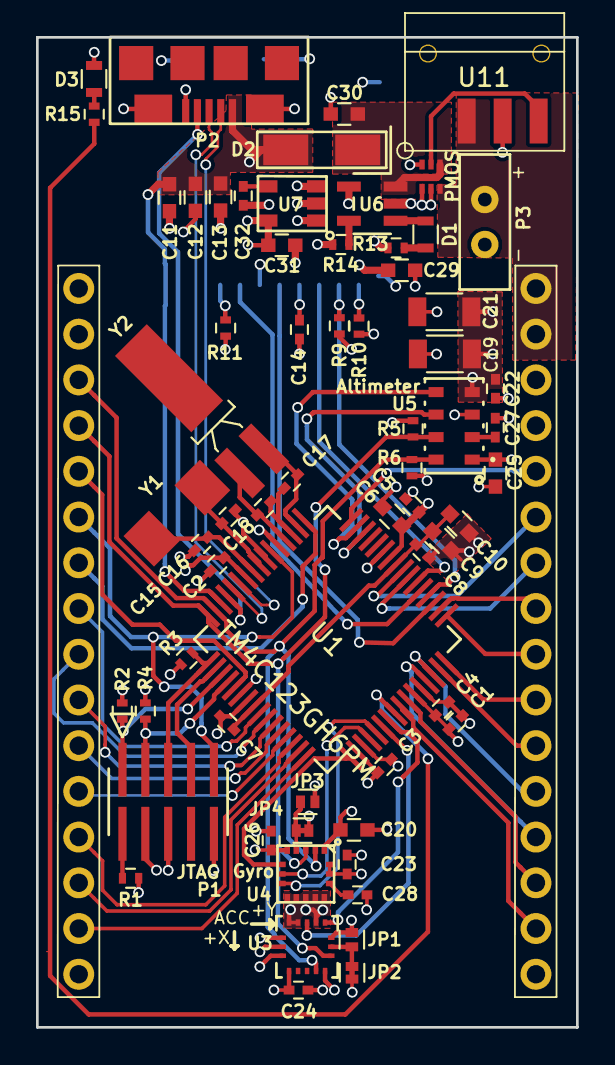
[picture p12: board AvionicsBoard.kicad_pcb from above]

Board: 4 copper layers, 30.0 x 55.0 mm, 67 parts (1 on the bottom side), 67 nets.

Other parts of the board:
U10: DMG1029SV-7; SOT563
U11: CSS-1210TB
microSD_Card: microSD_Card; Micro_SD_WM11190CT

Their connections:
+VBAT: U10.6, U11.1; also elsewhere on the board
+VBAT_ON: U10.1; also elsewhere on the board
ACC_CS: microSD_Card.4; also elsewhere on the board
unnamed 10: microSD_Card.1; also elsewhere on the board
unnamed 11: microSD_Card.8; also elsewhere on the board
PA2/SDCLK: microSD_Card.5; also elsewhere on the board
PA3/SD~CS: microSD_Card.2; also elsewhere on the board
PA4/SDDO: microSD_Card.7; also elsewhere on the board
PA5/SDDI: microSD_Card.3; also elsewhere on the board
PWR_GND: U10.3, U10.4, U10.5, U11.2, microSD_Card.6, microSD_Card.9, microSD_Card.10, microSD_Card.11, microSD_Card.12; also elsewhere on the board
PWR_SWITCH: U10.2, U11.3

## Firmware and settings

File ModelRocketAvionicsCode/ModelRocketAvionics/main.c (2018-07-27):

#include "stdint.h"
#include "stdbool.h"

//#include "inc/hw_types.h"
//#include "inc/hw_memmap.h"

#include "sch.h"
#include "ser.h"

//#############################################//
//                    Defines
//#############################################//



//#############################################//
//                   Variables
//#############################################//

extern uint32_t currentTime;

//#############################################//
//                 User Functions
//#############################################//

uint8_t Task_StatusUpdate_Init(void) {
    //Nothing to initialize
    return 0;
}

_Bool Task_StatusUpdate_Exec(uint8_t taskID){
    //Super basic taskExample, send the current time every second
    SerialPrintlnInt(currentTime);

    // Returns true to set the task back to IDLE state
    return true;
}

/*
 * SerialOnCharReceived(character)
 *  Function to handle received character events over serial
 * This function is called in an interrupt, keep its exec time really short or use..
 *  other non-interrupt functions.
 */
void SerialOnCharReceived(char character) {
    //Echo the character
    SerialWrite(character);
}

/*
 * SerialOnCharReceived(character)
 *  Function to handle received line events over serial configure the line endings..
 *   in the #define section found in ser.c.
 *  This function is called in an interrupt, keep its exec time really short or use..
 *   other non-interrupt functions.
 */
void SerialOnLineReceived(volatile char* stringStart, volatile char* stringEnd) {
    //Do nothing.. Below snippet is provided as an example

    /*
    uint8_t length = stringEnd - stringStart;

    char *character;
    for (character = stringStart; character < stringEnd; character++) {
        //Iterate through each character (useful if you want to do command parsing)..
    }
    */
}

//#############################################//
//                     Setup()
//#############################################//
void Setup(void) {
    // Add peripheral initializations here
    InitScheduler();
    InitSerial(&SerialOnCharReceived, &SerialOnLineReceived);

    // Add Tasks Here
    AddTaskTime(&Task_StatusUpdate_Init, &Task_StatusUpdate_Exec, 1000);

    //
}


//#############################################//
//                     Loop()
//#############################################//
void Loop(void) {
    UpdateScheduler();
}


//#############################################//
//                  Main Function
//#############################################//
/*  You shouldn't need to edit anything here as..
 *   its brought out to Setup() and Loop().
 */
int main(void) {
    Setup();
    while(1){
        Loop();
    }
}

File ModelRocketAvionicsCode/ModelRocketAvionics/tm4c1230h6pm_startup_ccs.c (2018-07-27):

//*****************************************************************************
//
// Startup code for use with TI's Code Composer Studio.
//
// Copyright (c) 2011-2014 Texas Instruments Incorporated.  All rights reserved.
// Software License Agreement
// 
// Software License Agreement
//
// Texas Instruments (TI) is supplying this software for use solely and
// exclusively on TI's microcontroller products. The software is owned by
// TI and/or its suppliers, and is protected under applicable copyright
// laws. You may not combine this software with "viral" open-source
// software in order to form a larger program.
//
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
//*****************************************************************************

#include <stdint.h>

//*****************************************************************************
//
// Forward declaration of the default fault handlers.
//
//*****************************************************************************
void ResetISR(void);
static void NmiSR(void);
static void FaultISR(void);
static void IntDefaultHandler(void);

//*****************************************************************************
//
// External declaration for the reset handler that is to be called when the
// processor is started
//
//*****************************************************************************
extern void _c_int00(void);

//*****************************************************************************
//
// Linker variable that marks the top of the stack.
//
//*****************************************************************************
extern uint32_t __STACK_TOP;

//*****************************************************************************
//
// External declarations for the interrupt handlers used by the application.
//
//*****************************************************************************
extern void SysTickInterruptHandler(void);
extern void SerialInterruptHandler(void);

//*****************************************************************************
//
// The vector table.  Note that the proper constructs must be placed on this to
// ensure that it ends up at physical address 0x0000.0000 or at the start of
// the program if located at a start address other than 0.
//
//*****************************************************************************
#pragma DATA_SECTION(g_pfnVectors, ".intvecs")
void (* const g_pfnVectors[])(void) =
{
    (void (*)(void))((uint32_t)&__STACK_TOP),
                                            // The initial stack pointer
    ResetISR,                               // The reset handler
    NmiSR,                                  // The NMI handler
    FaultISR,                               // The hard fault handler
    IntDefaultHandler,                      // The MPU fault handler
    IntDefaultHandler,                      // The bus fault handler
    IntDefaultHandler,                      // The usage fault handler
    0,                                      // Reserved
    0,                                      // Reserved
    0,                                      // Reserved
    0,                                      // Reserved
    IntDefaultHandler,                      // SVCall handler
    IntDefaultHandler,                      // Debug monitor handler
    0,                                      // Reserved
    IntDefaultHandler,                      // The PendSV handler
    SysTickInterruptHandler,               // The SysTick handler
    IntDefaultHandler,                      // GPIO Port A
    IntDefaultHandler,                      // GPIO Port B
    IntDefaultHandler,                      // GPIO Port C
    IntDefaultHandler,                      // GPIO Port D
    IntDefaultHandler,                      // GPIO Port E
    SerialInterruptHandler,                // UART0 Rx and Tx
    IntDefaultHandler,                      // UART1 Rx and Tx
    IntDefaultHandler,                      // SSI0 Rx and Tx
    IntDefaultHandler,                      // I2C0 Master and Slave
    IntDefaultHandler,                      // PWM Fault
    IntDefaultHandler,                      // PWM Generator 0
    IntDefaultHandler,                      // PWM Generator 1
    IntDefaultHandler,                      // PWM Generator 2
    IntDefaultHandler,                      // Quadrature Encoder 0
    IntDefaultHandler,                      // ADC Sequence 0
    IntDefaultHandler,                      // ADC Sequence 1
    IntDefaultHandler,                      // ADC Sequence 2
    IntDefaultHandler,                      // ADC Sequence 3
    IntDefaultHandler,                      // Watchdog timer
    IntDefaultHandler,                      // Timer 0 subtimer A
    IntDefaultHandler,                      // Timer 0 subtimer B
    IntDefaultHandler,                      // Timer 1 subtimer A
    IntDefaultHandler,                      // Timer 1 subtimer B
    IntDefaultHandler,                      // Timer 2 subtimer A
    IntDefaultHandler,                      // Timer 2 subtimer B
    IntDefaultHandler,                      // Analog Comparator 0
    IntDefaultHandler,                      // Analog Comparator 1
    IntDefaultHandler,                      // Analog Comparator 2
    IntDefaultHandler,                      // System Control (PLL, OSC, BO)
    IntDefaultHandler,                      // FLASH Control
    IntDefaultHandler,                      // GPIO Port F
    IntDefaultHandler,                      // GPIO Port G
    IntDefaultHandler,                      // GPIO Port H
    IntDefaultHandler,                      // UART2 Rx and Tx
    IntDefaultHandler,                      // SSI1 Rx and Tx
    IntDefaultHandler,                      // Timer 3 subtimer A
    IntDefaultHandler,                      // Timer 3 subtimer B
    IntDefaultHandler,                      // I2C1 Master and Slave
    IntDefaultHandler,                      // Quadrature Encoder 1
    IntDefaultHandler,                      // CAN0
    IntDefaultHandler,                      // CAN1
    0,                                      // Reserved
    0,                                      // Reserved
    IntDefaultHandler,                      // Hibernate
    IntDefaultHandler,                      // USB0
    IntDefaultHandler,                      // PWM Generator 3
    IntDefaultHandler,                      // uDMA Software Transfer
    IntDefaultHandler,                      // uDMA Error
    IntDefaultHandler,                      // ADC1 Sequence 0
    IntDefaultHandler,                      // ADC1 Sequence 1
    IntDefaultHandler,                      // ADC1 Sequence 2
    IntDefaultHandler,                      // ADC1 Sequence 3
    0,                                      // Reserved
    0,                                      // Reserved
    IntDefaultHandler,                      // GPIO Port J
    IntDefaultHandler,                      // GPIO Port K
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

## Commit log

2018-04-28 Schematic Started
    [AvionicsBoard.kicad_pcb, AvionicsBoard.sch]
2018-04-30 Compiled sensors on another Sheet, added uSD card/flash chip, jtag interface, power supply filter caps and started to add USB OTG
    [AvionicsBoard.sch, Sensors.sch]
2018-05-01 Added oscillators and reset button/circuit
    [AvionicsBoard.sch]
2018-05-01 Critical features/components of avionics board schematic are complete (needs review). Still need to figure out a logical expansion header pinout and place the headers.
    [AvionicsBoard.sch, Power.sch, Sensors.sch]
2018-05-01 Added IMU interrupt pin wiring to TODO and created a basic PDF of the current schematic
    [AvionicsBoard.sch]
2018-05-01 Annotated components and added 'Digi-Key Part Numbers' for most of the non-passives
    [AvionicsBoard.sch, Power.sch, Sensors.sch]
2018-05-28 Added pin allocation excel sheet for planning/documentation
    [AvionicsBoard.sch, Power.sch, Sensors.sch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]
2018-05-28 Added User switches and LED to the pcb schematic
    [AvionicsBoard.sch, Power.sch, Sensors.sch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]
2018-05-30 oh no
    [AvionicsBoard.sch, PM0064A.stp, Power.sch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]
2018-05-30 Added footprint for RTC crystal
2018-05-31 Added Footprints for non-passives
    [AvionicsBoard.sch, Power.sch, Sensors.sch]
2018-06-06 Footprints Completed
    Except Jumper Footprints
    [AvionicsBoard.sch, Power.sch, Sensors.sch]
2018-06-06 Changed polarized caps to use 1206 and digikey part number: 478-10756-1-ND
    [Sensors.sch]
2018-06-07 Began Preliminary Layout
    [AvionicsBoard.kicad_pcb, Sensors.sch, TM4C Pin Diagram.xlsx]
2018-06-16 Completed Preliminary Layout
    [AvionicsBoard.kicad_pcb, AvionicsBoard.sch, TM4C Pin Diagram.xlsx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]
2018-07-13 Added 16 pin Female Headers
2018-07-14 Partially Complete Updated Avionics Layout
    Final Pinout and Silk Screen still needs to be completed.
    [AvionicsBoard.kicad_pcb, AvionicsBoard.sch, _saved_AvionicsBoard.sch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]
2018-07-14 CDR Ready Board
    [AvionicsBoard.kicad_pcb, TM4C Pin Diagram.xlsx, _saved_AvionicsBoard.sch]
2018-07-15 Updated Sch
    [AvionicsBoard.sch, PWRSwitch.sch, Power.sch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]
2018-07-15 Schematic Check Complete
    [AvionicsBoard.sch, Power.sch, Sensors.sch]
2018-07-15 DRC Issues Solved
    [AvionicsBoard.kicad_pcb]
2018-07-15 CDR Complete
    [AvionicsBoard.kicad_pcb]
2018-07-16 Created a new PDF file of the schematic for reference
2018-07-17 Final Board REV 1a - Gerber Files
    [AvionicsBoard-B.Adhes.gbr, AvionicsBoard-B.Cu.gbr, AvionicsBoard-B.Mask.gbr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]
2018-07-19 Updated for certainity
    [AvionicsBoard-B.Adhes.gbr, AvionicsBoard-B.Cu.gbr, AvionicsBoard-B.Mask.gbr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]
2018-07-26 First real commit! Started writing the Scheduler (sch.c/.h), currently untested. See TIVA C Worksbook Lab2 for IDE setup instructions.
2018-07-27 Started doing SPI, CC2500 and Serial support, still untested

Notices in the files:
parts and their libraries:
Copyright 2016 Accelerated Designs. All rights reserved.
